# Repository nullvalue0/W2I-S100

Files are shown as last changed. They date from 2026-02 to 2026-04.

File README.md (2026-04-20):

S-100 Board Version of Mike Arnold's W2I (WDI to IDE adapter), for emulating up to four 11Mb IMI7710A drives. It is compatible with CDOS, Z80 Cromix, 68000 Cromix and Cromix Plus. It works with the Cromemco WDI and WDI-II controller. 

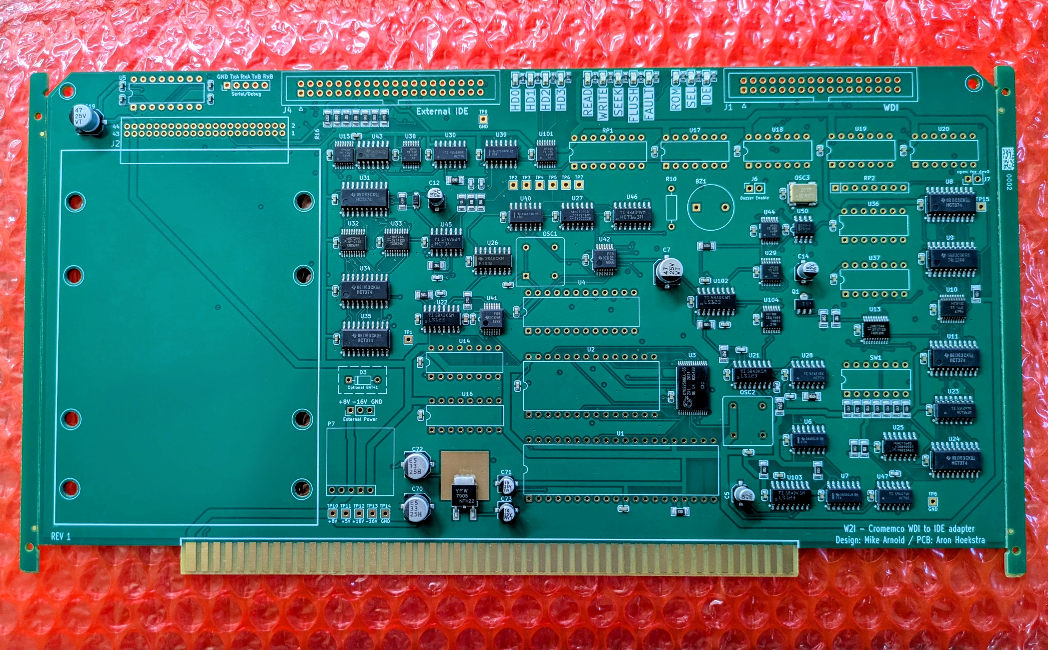
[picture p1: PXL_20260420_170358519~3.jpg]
First Prototype Photo


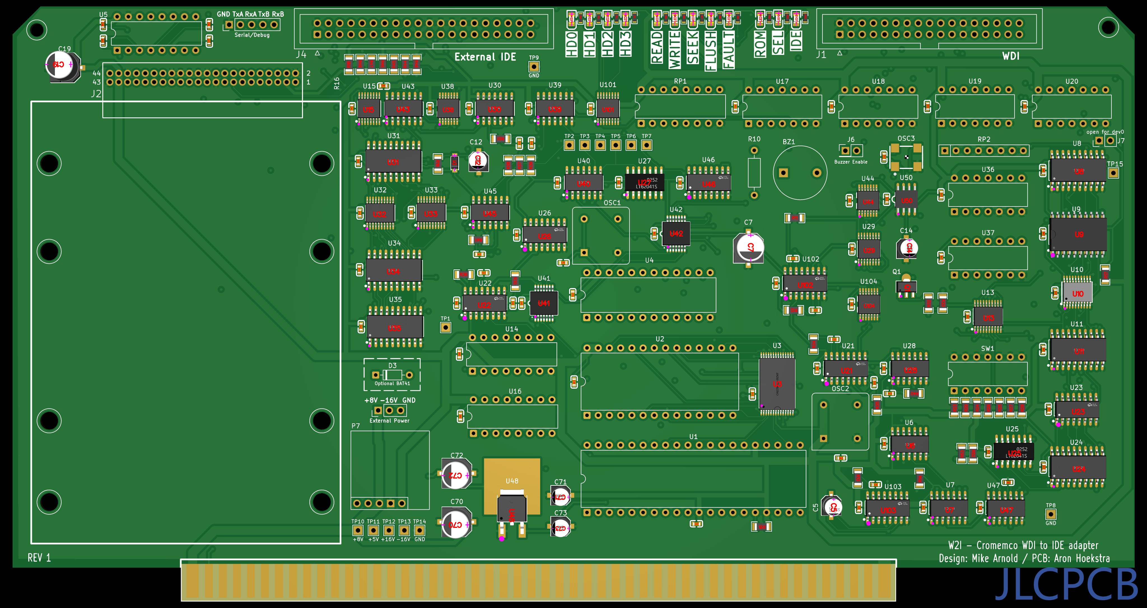
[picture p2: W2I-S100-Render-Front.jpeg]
PCB Front Render


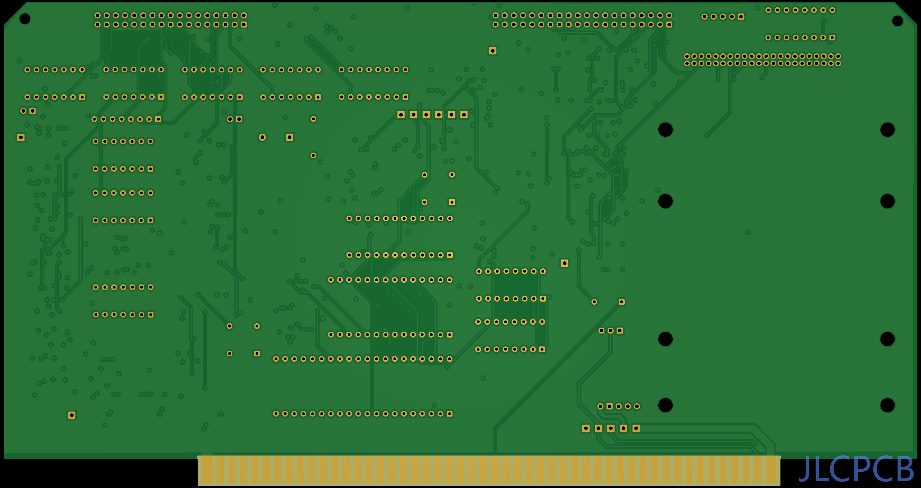
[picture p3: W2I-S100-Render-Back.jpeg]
PCB Back Render


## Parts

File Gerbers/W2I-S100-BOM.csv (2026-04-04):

Reference | Qty | Value | LCSC Part | DNP | Exclude from BOM | Exclude from Board | Footprint | Datasheet
BZ1 | 1 | PKHPS0013E4000-A2 |  |  |  |  | Buzzer_Beeper:Buzzer_12x9.5RM7.6 | ~
C1,C6,C8,C9,C10,C11,C13,C15,C16,C17,C18,C24,C25,C26,C27,C28,C29,C30,C31,C32,C36,C37,C38,C40,C41,C42,C44,C45,C46,C47,C48,C49,C50,C51,C52,C53,C54,C55,C56,C57,C58,C59,C60,C61,C62,C63,C64,C65,C66,C67,C68,C69,C74,C75,C77,C78 | 56 | 0.1uF | C1590 |  |  |  | footprints:C0603 | https://lcsc.com/product-detail/Multilayer-Ceramic-Capacitors-MLCC-SMD-SMT_SAMSUNG_CL10B104KA8NNNC_100nF-104-10-25V_C1590.html
C2,C3,C4 | 3 | 1.0uF | C29936 |  |  |  | footprints:C0603 | https://lcsc.com/product-detail/Multilayer-Ceramic-Capacitors-MLCC-SMD-SMT_SAMSUNG_CL10B104KA8NNNC_100nF-104-10-25V_C1590.html
C5 | 1 | 4.7uF | C264246 |  |  |  | footprints:CAP-SMD_BD4.0-L4.3-W4.3-LS5.3-FD | https://lcsc.com/product-detail/Others_Semtech-CK1E4R7M0405_C264246.html
C7,C19 | 2 | 47uF | C141425 |  |  |  | footprints:CAP-SMD_BD6.3-L6.6-W6.6-FD | https://lcsc.com/product-detail/Aluminum-Electrolytic-Capacitors-SMD_47uF-20-25V_C141425.html
C12,C14,C71,C73 | 4 | 10uF | C3343 |  |  |  | footprints:CAP-SMD_BD4.0-L4.3-W4.3-FD | https://lcsc.com/product-detail/Aluminum-Electrolytic-Capacitors-SMD_10uF-25V_C3343.html
C20 | 1 | 22uF | C2762594 |  |  |  | footprints:C0603
C21,C22,C23 | 3 | 470pF | C519395 |  |  |  | footprints:C0603 | ~
C33,C34,C35,C39 | 4 | 47pF | C519392 |  |  |  | footprints:C0603 | ~
C43 | 1 | 22pF | C519390 |  |  |  | footprints:C0603 | ~
C70,C72 | 2 | 33uF | C249892 |  |  |  | footprints:CAP-SMD_BD6.3-L6.6-W6.6-FD | https://lcsc.com/product-detail/Others_Lelon-VZH330M1E0606-TRO_C249892.html,https://lcsc.com/product-detail/Others_Semtech-CK1E4R7M0405_C264246.html
C76 | 1 | .33uF | C1615 |  |  |  | footprints:C0603 | https://lcsc.com/product-detail/Multilayer-Ceramic-Capacitors-MLCC-SMD-SMT_330nF-334-10-25V_C1615.html
D1 | 1 | 1N4148W T4 | C2099 |  |  |  | footprints:SOD-123_L2.8-W1.8-LS3.7-RD | https://lcsc.com/product-detail/Switching-Diode_1N4148W-T4_C2099.html
D3 | 1 | BAT41 |  |  |  |  | Diode_THT:D_DO-35_SOD27_P7.62mm_Horizontal | http://www.vishay.com/docs/85659/bat41.pdf
J1 | 1 | to WDI |  |  |  |  | Connector_IDC:IDC-Header_2x17_P2.54mm_Vertical | SBH11-PBPC-D17-ST-BK
J2 | 1 | 44-pin IDE |  |  |  |  | footprints:SAMTEC-SQT-122-01-X-D-RA
J3 | 1 | Serial |  |  |  |  | Connector_PinHeader_2.54mm:PinHeader_1x05_P2.54mm_Vertical | ~
J4 | 1 | 40-pin IDE |  |  |  |  | Connector_IDC:IDC-Header_2x20_P2.54mm_Vertical | ~
J5 | 1 | EXT PWR |  |  |  |  | Connector_PinHeader_2.54mm:PinHeader_1x03_P2.54mm_Vertical | ~
J6 | 1 | Jumper to enable buzzer |  |  |  |  | Connector_PinHeader_2.54mm:PinHeader_2x01_P2.54mm_Vertical | ~
J7 | 1 | Conn_01x02_Pin |  |  |  |  | Connector_PinHeader_2.54mm:PinHeader_1x02_P2.54mm_Vertical | ~
LED1,LED2,LED3,LED4 | 4 | YELLOW | C84261 |  |  |  | footprints:LED0805-R-RD | https://lcsc.com/product-detail/Light-Emitting-Diodes-LED_Yellow-light-SMDLED-80-150mcd_C84261.html
LED5,LED7,LED8 | 3 | GREEN | C84260 |  |  |  | footprints:LED0805-R-RD | https://lcsc.com/product-detail/Light-Emitting-Diodes-LED_Emerald-SMDLED-180-330mcd_C84260.html
LED6,LED9,LED11,LED12,LED13 | 5 | RED | C84256 |  |  |  | footprints:LED0805-R-RD | https://lcsc.com/product-detail/Light-Emitting-Diodes-LED_Red-LED-SMDLED-80-180mcd_C84256.html
OSC1 | 1 | ECS-2100AX-3.6864MHZ |  |  |  |  | Oscillator:Oscillator_DIP-8 | http://cdn-reichelt.de/documents/datenblatt/B400/OSZI.pdf
OSC2 | 1 | ACHL-27.000MHZ-EK |  |  |  |  | Oscillator:Oscillator_DIP-8 | http://cdn-reichelt.de/documents/datenblatt/B400/OSZI.pdf
OSC3 | 1 | 22.5792MHz | C7431407 |  |  |  | footprints:OSC-SMD_4P-L7.0-W5.0-BL-2
P1 | 1 | S100_MALE
P7 | 1 | 5V Reg |  |  |  |  | Connector_PinHeader_2.54mm:PinHeader_1x05_P2.54mm_Vertical | ~
Q1 | 1 | 2N2222AU | C21714170 |  |  |  | footprints:SOT-89-3_L4.5-W2.4-P1.50-LS4.0-BR
R1,R2,R3,R4 | 4 | 270 | C22966 |  |  |  | footprints:R0603 | https://lcsc.com/product-detail/Chip-Resistor-Surface-Mount-UniOhm_270R-2700-1_C22966.html
R5,R7,R8 | 3 | 160 | C22814 |  |  |  | footprints:R0603 | https://lcsc.com/product-detail/Chip-Resistor-Surface-Mount-UniOhm_470R-4700-1_C4502.html
R6,R9,R22,R31,R50 | 5 | 360 | C25194 |  |  |  | footprints:R0603 | https://lcsc.com/product-detail/Chip-Resistor-Surface-Mount-UniOhm_360R-3600-1_C25194.html
R10 | 1 | 330 |  |  |  |  | Resistor_THT:R_Axial_DIN0207_L6.3mm_D2.5mm_P10.16mm_Horizontal | ~
R11,R12,R13 | 3 | 100K | C17900 |  |  |  | footprints:R1206 | https://lcsc.com/product-detail/Chip-Resistor-Surface-Mount-UniOhm_100KR-1003-1_C17900.html
R14,R30 | 2 | 270K | C17940 |  |  |  | footprints:R1206 | https://lcsc.com/product-detail/Chip-Resistor-Surface-Mount-UniOhm_270KR-2703-1_C17940.html
R15,R17,R23,R24,R25,R26,R27,R28,R29 | 9 | 4.7K | C17936 |  |  |  | footprints:R1206 | https://lcsc.com/product-detail/Chip-Resistor-Surface-Mount-UniOhm_15KR-1502-1_C25828.html,https://lcsc.com/product-detail/Chip-Resistor-Surface-Mount-UniOhm_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
R16 | 1 | 22K | C114942 |  |  |  | footprints:R1206 | https://lcsc.com/product-detail/Chip-Resistor-Surface-Mount-UniOhm_5-6KR-5601-1_C18028.html
R18 | 1 | 47K | C25833 |  |  |  | footprints:R1206 | https://lcsc.com/product-detail/Chip-Resistor-Surface-Mount-UniOhm_47KR-4702-1_C25833.html
R32 | 1 | 2.2K | C17948 |  |  |  | footprints:R1206 | https://lcsc.com/product-detail/Chip-Resistor-Surface-Mount-UniOhm_2-2KR-2201-1_C17948.html
R33,R37,R39,R41,R46,R47,R52 | 7 | 1K | C1469 |  |  |  | footprints:R1206 | https://lcsc.com/product-detail/Chip-Resistor-Surface-Mount-UniOhm_1KR-102-5_C1469.html
R34,R35,R36 | 3 | 15K | C25828 |  |  |  | footprints:R1206 | https://lcsc.com/product-detail/Chip-Resistor-Surface-Mount-UniOhm_15KR-1502-1_C25828.html
R38,R53 | 2 | 1.5K | C26030 |  |  |  | footprints:R1206 | https://lcsc.com/product-detail/Chip-Resistor-Surface-Mount-UniOhm_1-5KR-1501-1_C26030.html
R40 | 1 | 470 | C4502 |  |  |  | footprints:R1206 | https://lcsc.com/product-detail/Chip-Resistor-Surface-Mount-UniOhm_470R-4700-1_C4502.html
R44,R45 | 2 | 33 | C18005 |  |  |  | footprints:R1206 | https://lcsc.com/product-detail/Chip-Resistor-Surface-Mount-UniOhm_33R-33R0-1_C18005.html
R48 | 1 | 5.6K | C18028 |  |  |  | footprints:R1206 | https://lcsc.com/product-detail/Chip-Resistor-Surface-Mount-UniOhm_5-6KR-5601-1_C18028.html
R49 | 1 | 10K | C17902 |  |  |  | footprints:R1206 | https://lcsc.com/product-detail/Chip-Resistor-Surface-Mount-UniOhm_10KR-1002-1_C17902.html
R51 | 1 | 100 | C17901 |  |  |  | footprints:R1206 | https://lcsc.com/product-detail/Chip-Resistor-Surface-Mount-UniOhm_100R-1000-1_C17901.html
RP1 | 1 | 4116R-3-221/331 |  |  |  |  | Package_DIP:DIP-16_W7.62mm | ~
RP2 | 1 | 4x100Ω |  |  |  |  | Resistor_THT:R_Array_SIP8 | http://www.vishay.com/docs/31509/csc.pdf
SW1 | 1 | SW_DIP_x07 |  |  |  |  | Package_DIP:DIP-14_W7.62mm | ~
TP1 | 1 | 2s timer output |  |  |  |  | TestPoint:TestPoint_THTPad_2.0x2.0mm_Drill1.0mm | ~
TP2 | 1 | 50ns W60h pulse |  |  |  |  | TestPoint:TestPoint_THTPad_2.0x2.0mm_Drill1.0mm | ~
TP3 | 1 | 50ns R60h pulse |  |  |  |  | TestPoint:TestPoint_THTPad_2.0x2.0mm_Drill1.0mm | ~
TP4 | 1 | 50ns delayed W60h pulse |  |  |  |  | TestPoint:TestPoint_THTPad_2.0x2.0mm_Drill1.0mm | ~
TP5 | 1 | 50ns burst clock trigger |  |  |  |  | TestPoint:TestPoint_THTPad_2.0x2.0mm_Drill1.0mm | ~
TP6 | 1 | 50ns primer clock trigger |  |  |  |  | TestPoint:TestPoint_THTPad_2.0x2.0mm_Drill1.0mm | ~
TP7 | 1 | 22.579MHz clock |  |  |  |  | TestPoint:TestPoint_THTPad_2.0x2.0mm_Drill1.0mm | ~
TP8,TP9,TP14 | 3 | GND |  |  |  |  | TestPoint:TestPoint_THTPad_2.0x2.0mm_Drill1.0mm | ~
TP10 | 1 | +8V |  |  |  |  | TestPoint:TestPoint_THTPad_2.0x2.0mm_Drill1.0mm | ~
TP11 | 1 | +5V |  |  |  |  | TestPoint:TestPoint_THTPad_2.0x2.0mm_Drill1.0mm | ~
TP12 | 1 | +16V |  |  |  |  | TestPoint:TestPoint_THTPad_2.0x2.0mm_Drill1.0mm | ~
TP13 | 1 | -16V |  |  |  |  | TestPoint:TestPoint_THTPad_2.0x2.0mm_Drill1.0mm | ~
TP15 | 1 | U8-16 |  |  |  |  | TestPoint:TestPoint_THTPad_2.0x2.0mm_Drill1.0mm | ~
U1 | 1 | Z84C0020PEC |  |  |  |  | Package_DIP:DIP-40_W15.24mm | www.zilog.com/manage_directlink.php?filepath=docs/z80/um0080
U2 | 1 | 28C256 |  |  |  |  | Package_DIP:DIP-28_W15.24mm | http://ww1.microchip.com/downloads/en/DeviceDoc/doc0006.pdf
U3 | 1 | CY62256NLL-55ZXIT | C2759940 |  |  |  | footprints:TSOP-28_L11.8-W8.0-P0.55-LS13.4-B_CYPRESS
U4 | 1 | 2681 |  |  |  |  | Package_DIP:DIP-24_W10.16mm | ~
U5 | 1 | MAX232A |  |  |  |  | Package_DIP:DIP-16_W7.62mm | http://www.ti.com/lit/ds/symlink/max232.pdf
U6,U7 | 2 | 74F74 | C6805 |  |  |  | footprints:SOIC-14_L8.7-W3.9-P1.27-LS6.0-BL | https://lcsc.com/product-detail/74-Series_TI_SN74F74DR_SN74F74DR_C6805.html
U8,U11,U24,U31,U34,U35 | 6 | 74HCT374 | C2677828 |  |  |  | footprints:SOP-20_L12.6-W5.3-P1.27-LS7.8-BL | https://www.ti.com/lit/ds/symlink/cd74hct374.pdf
U9 | 1 | 74LS244 | C22374097 |  |  |  | footprints:SOP-20_L12.6-W5.3-P1.27-LS7.8-BL | http://www.ti.com/lit/ds/symlink/sn74ls244.pdf
U10 | 1 | 74HCT240 | C543088 |  |  |  | footprints:TSSOP-20_L6.5-W4.4-P0.65-LS6.5-BL | https://assets.nexperia.com/documents/data-sheet/74HC_HCT240.pdf
U13,U32,U33 | 3 | 74HCT244 | C131088 |  |  |  | footprints:TSSOP-20_L6.5-W4.4-P0.65-LS6.4-BL | http://www.ti.com/lit/ds/symlink/sn74ls244.pdf
U14,U16 | 2 | 74F138 |  |  |  |  | Package_DIP:DIP-16_W7.62mm | http://www.ti.com/lit/gpn/sn74LS138
U15,U29,U101 | 3 | 74HCT138 | C8115 |  |  |  | footprints:TSSOP-16_L5.0-W4.4-P0.65-LS6.4-BL | http://www.ti.com/lit/ds/symlink/cd74hc238.pdf
U17,U18,U19,U20 | 4 | 7438 |  |  |  |  | Package_DIP:DIP-14_W7.62mm | http://www.ti.com/lit/gpn/sn74LS38
U21,U22,U102,U103 | 4 | 74LS123 | C234231 |  |  |  | footprints:SOIC-16_L9.9-W3.9-P1.27-LS6.0-BL | http://www.ti.com/lit/gpn/sn74LS123
U23 | 1 | 74HCT165 | C352828 |  |  |  | footprints:SOIC-16_L9.9-W3.9-P1.27-LS6.0-BL | https://assets.nexperia.com/documents/data-sheet/74HC_HCT165.pdf
U25 | 1 | 74HCT164 | C547397 |  |  |  | footprints:SOIC-14_L8.7-W3.9-P1.27-LS6.0-BL | https://assets.nexperia.com/documents/data-sheet/74HC_HCT164.pdf
U26 | 1 | 74F163 | C2675415 |  |  |  | footprints:SOIC-16_L9.9-W3.9-P1.27-LS6.0-BL
U27 | 1 | 74HCT393 | C547642 |  |  |  | footprints:SO-14_L8.7-W3.9-P1.27-LS6.0-BL | 74xx\74LS393.pdf
U28,U30 | 2 | 74HCT74 | C352961 |  |  |  | footprints:SO-14_L8.9-W3.9-P1.27-LS6.0-BL | https://assets.nexperia.com/documents/data-sheet/74HC_HCT74.pdf
U36 | 1 | 75107 |  |  |  |  | Package_DIP:DIP-14_W7.62mm | ~
U37 | 1 | 75110 |  |  |  |  | Package_DIP:DIP-14_W7.62mm | ~
U38,U44 | 2 | 74HCT04 | C131695 |  |  |  | footprints:TSSOP-14_L5.0-W4.4-P0.65-LS6.4-BL | https://assets.nexperia.com/documents/data-sheet/74HC_HCT04.pdf
U39 | 1 | 74F04 | C7159 |  |  |  | footprints:SOIC-14_L8.7-W3.9-P1.27-LS6.0-BL | https://lcsc.com/product-detail/74-Series_TI_SN74F04DR_SN74F04DR_C7159.html
U40 | 1 | 74F00 | C7158 |  |  |  | footprints:SOIC-14_L8.7-W3.9-P1.27-LS6.0-BL | https://lcsc.com/product-detail/74-Series_TI_SN74F00DR_SN74F00DR_C7158.html
U41,U42 | 2 | 74F08 | C4469192 |  |  |  | footprints:SSOP-14_L6.2-W5.3-P0.65-LS7.8-BL-1
U43 | 1 | 74HCT32 | C6781 |  |  |  | footprints:SOIC-14_L8.7-W3.9-P1.27-LS6.0-BL | http://www.ti.com/lit/gpn/sn74LS32
U45 | 1 | 74HCT14 | C6769 |  |  |  | footprints:SOIC-14_L8.7-W3.9-P1.27-LS6.0-BL | http://www.ti.com/lit/gpn/sn74LS14
U46 | 1 | 74HCT163 | C2866759 |  |  |  | footprints:SOIC-16_L9.9-W3.9-P1.27-LS6.0-BL | http://www.ti.com/lit/gpn/sn74LS163
U47 | 1 | 74HCT02 | C471050 |  |  |  | footprints:SOIC-14_L8.7-W3.9-P1.27-LS6.0-BL | http://www.ti.com/lit/gpn/sn74hct02
U48 | 1 | 7905 | C19273129 |  |  |  | footprints:TO-252-2_L6.6-W6.1-P4.57-LS10.1-BR-CW
U50 | 1 | 3.3V LDO Reg | C7301 |  |  |  | footprints:SOIC-8_L5.0-W4.0-P1.27-LS6.0-BL | https://lcsc.com/product-detail/Low-Dropout-Regulators-LDO_ON_MC33269DR2-3-3_MC33269DR2-3-3_C7301.html
U104 | 1 | 74HCT00 | C8206 |  |  |  | footprints:TSSOP-14_L5.0-W4.4-P0.65-LS6.4-BL | http://www.ti.com/lit/gpn/sn74hct00

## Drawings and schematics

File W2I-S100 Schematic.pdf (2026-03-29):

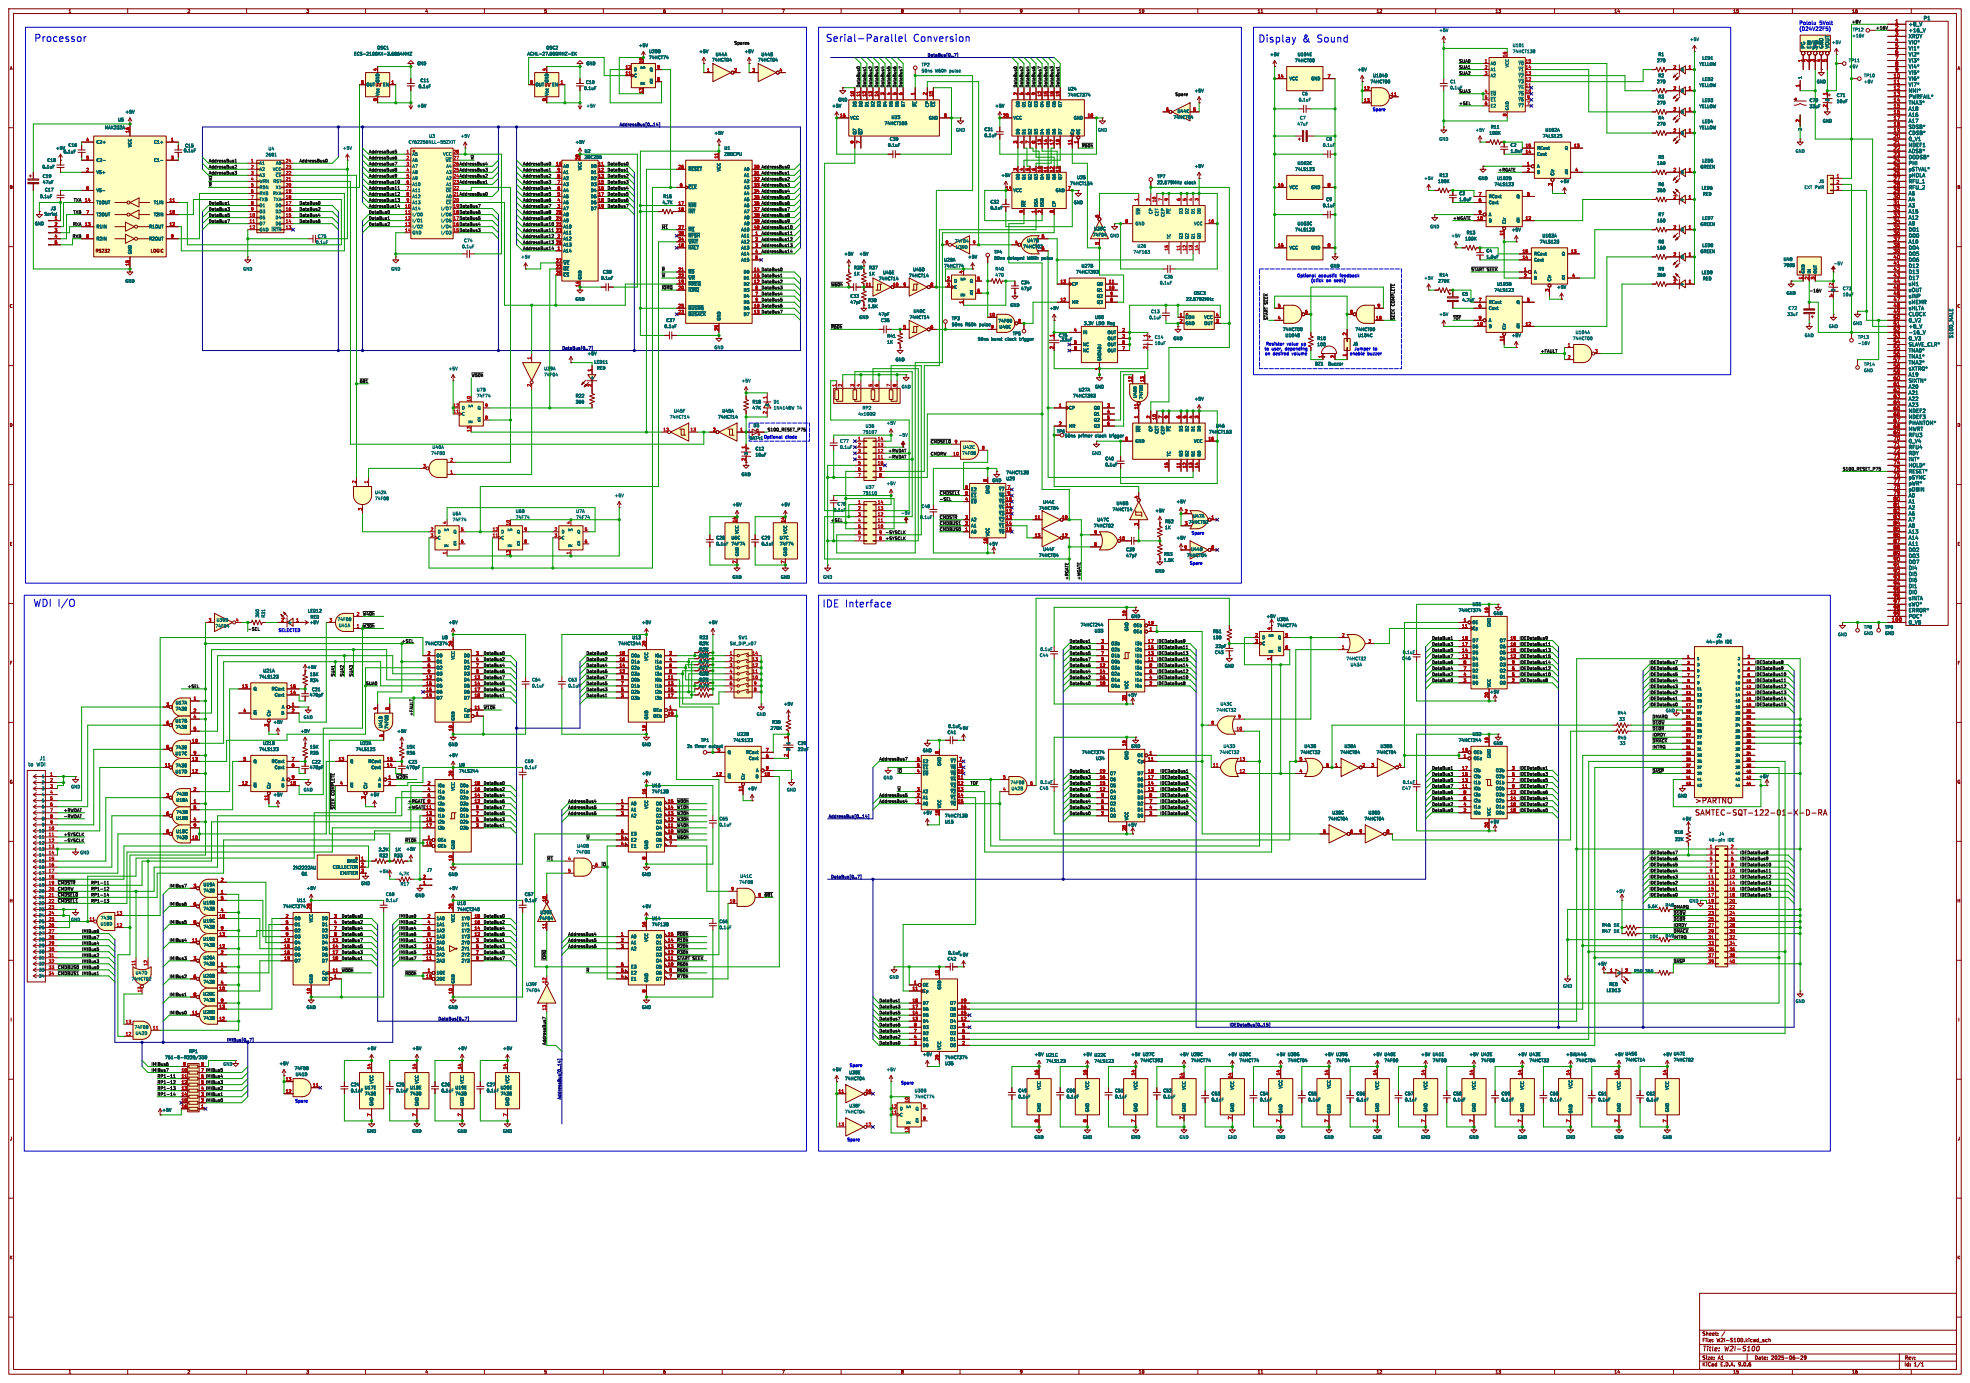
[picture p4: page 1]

9 ~{Q}8 OSC1 ECS-2100AX-3.6864MHZ EN 1 Vcc 8 GND

enable buzzer Resistor value up
to user, depending

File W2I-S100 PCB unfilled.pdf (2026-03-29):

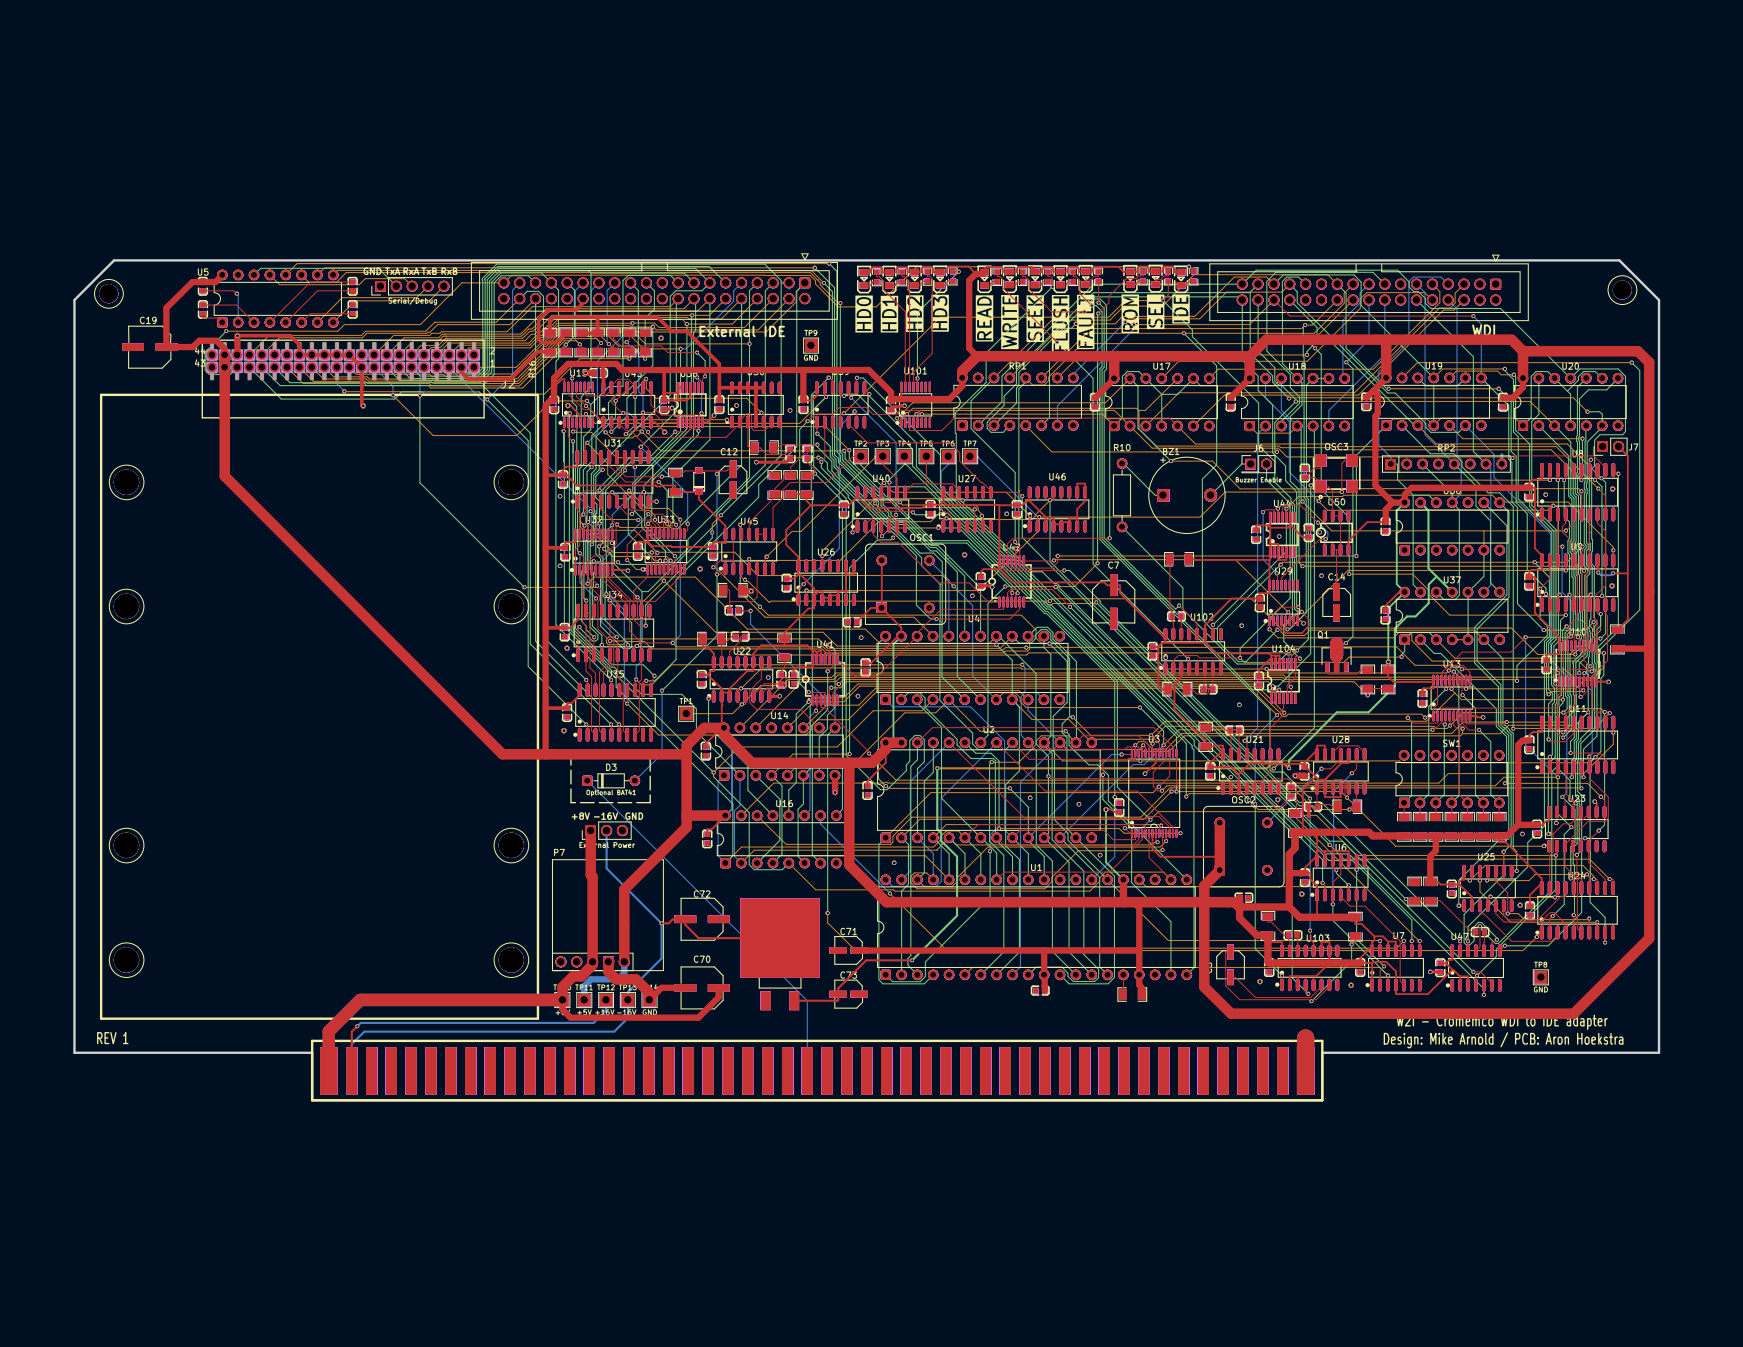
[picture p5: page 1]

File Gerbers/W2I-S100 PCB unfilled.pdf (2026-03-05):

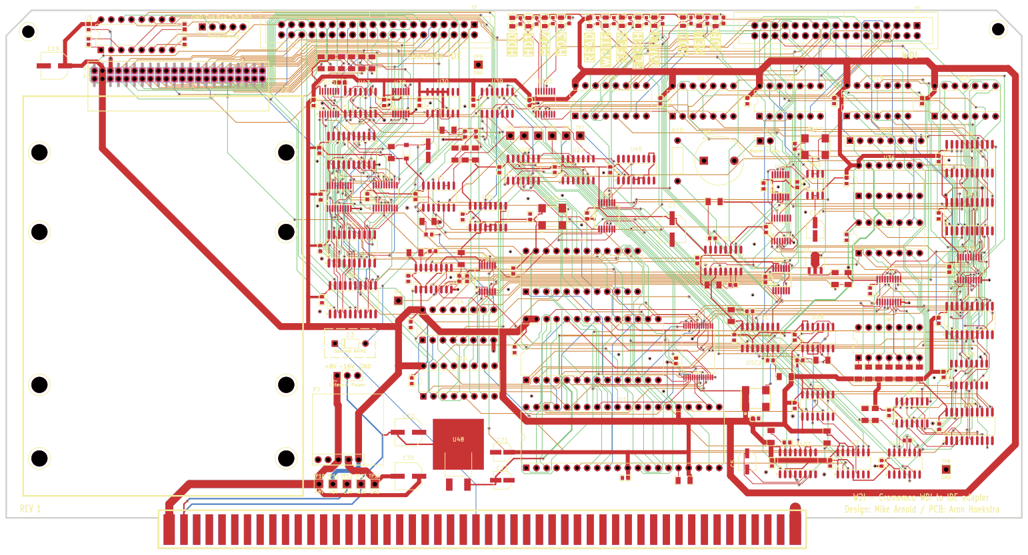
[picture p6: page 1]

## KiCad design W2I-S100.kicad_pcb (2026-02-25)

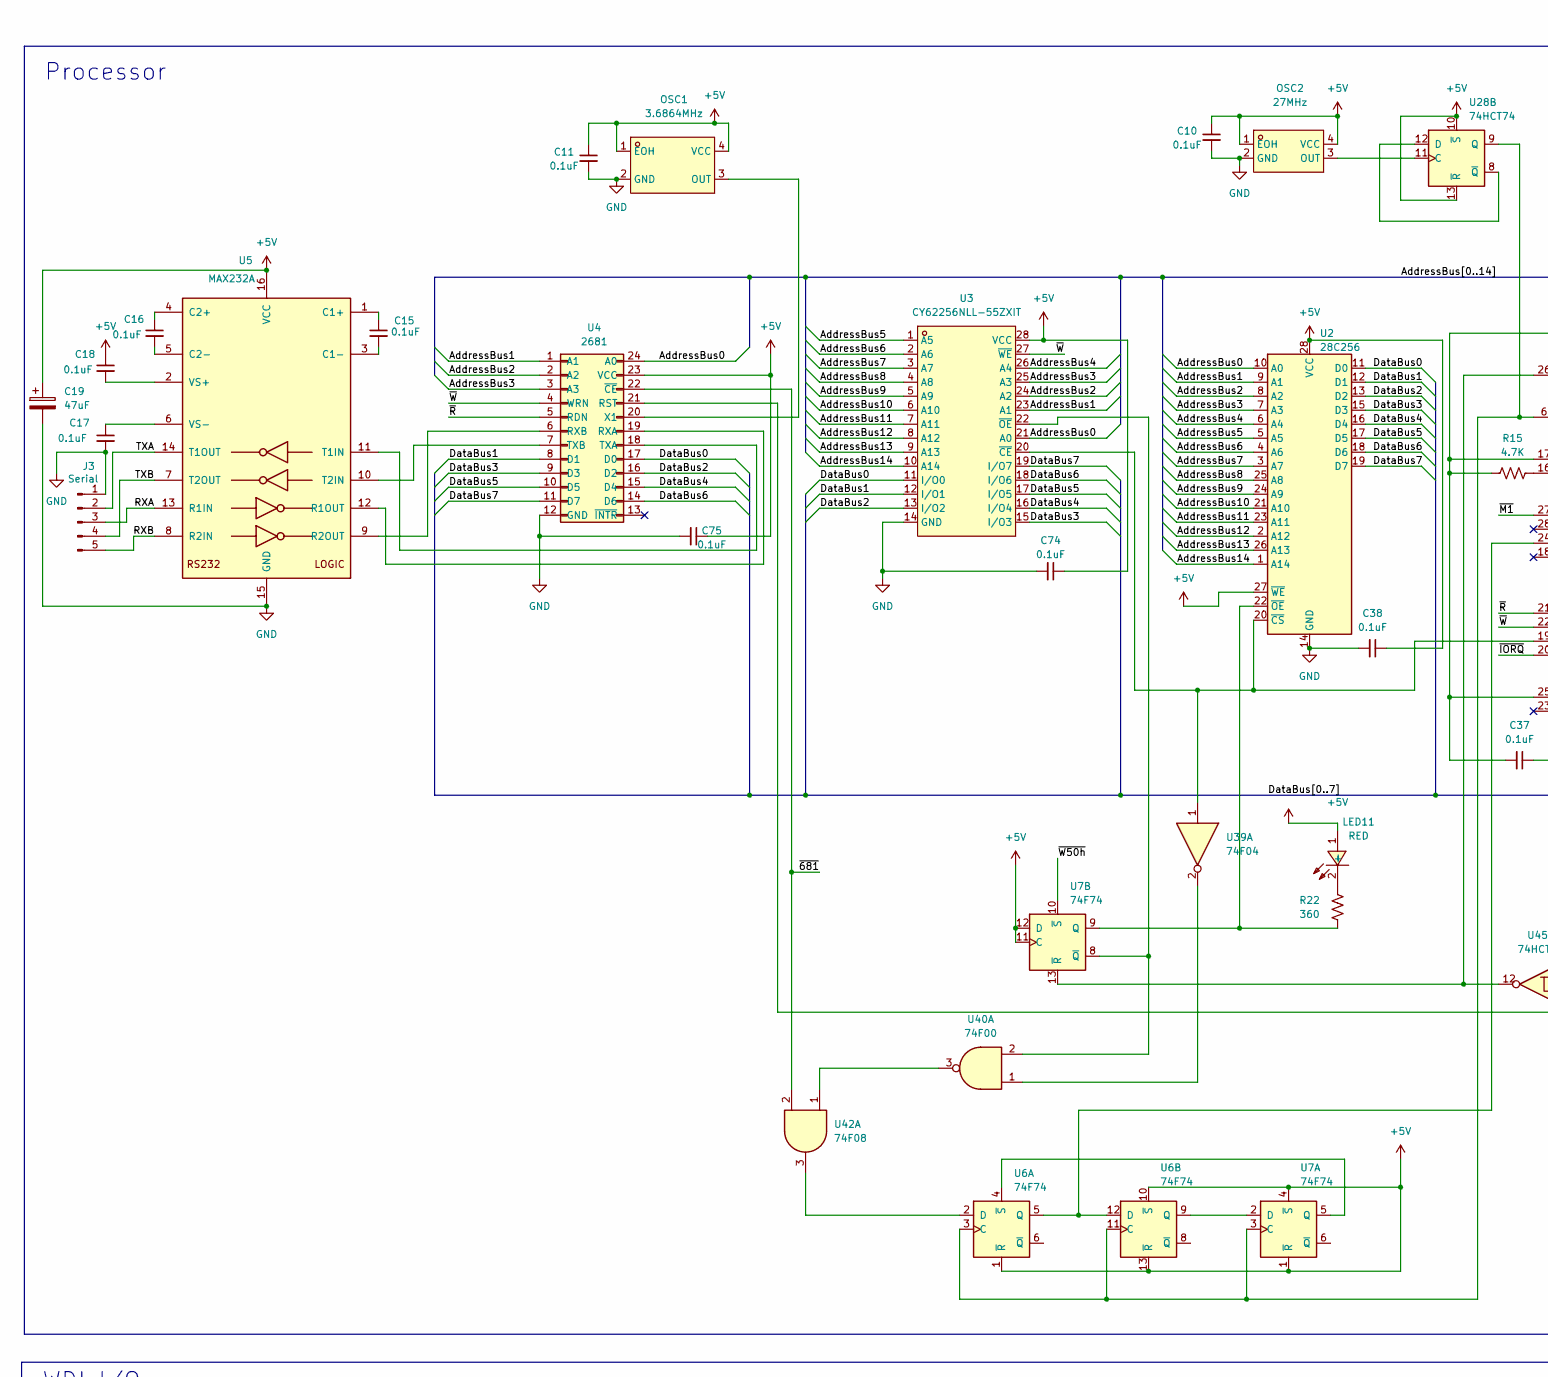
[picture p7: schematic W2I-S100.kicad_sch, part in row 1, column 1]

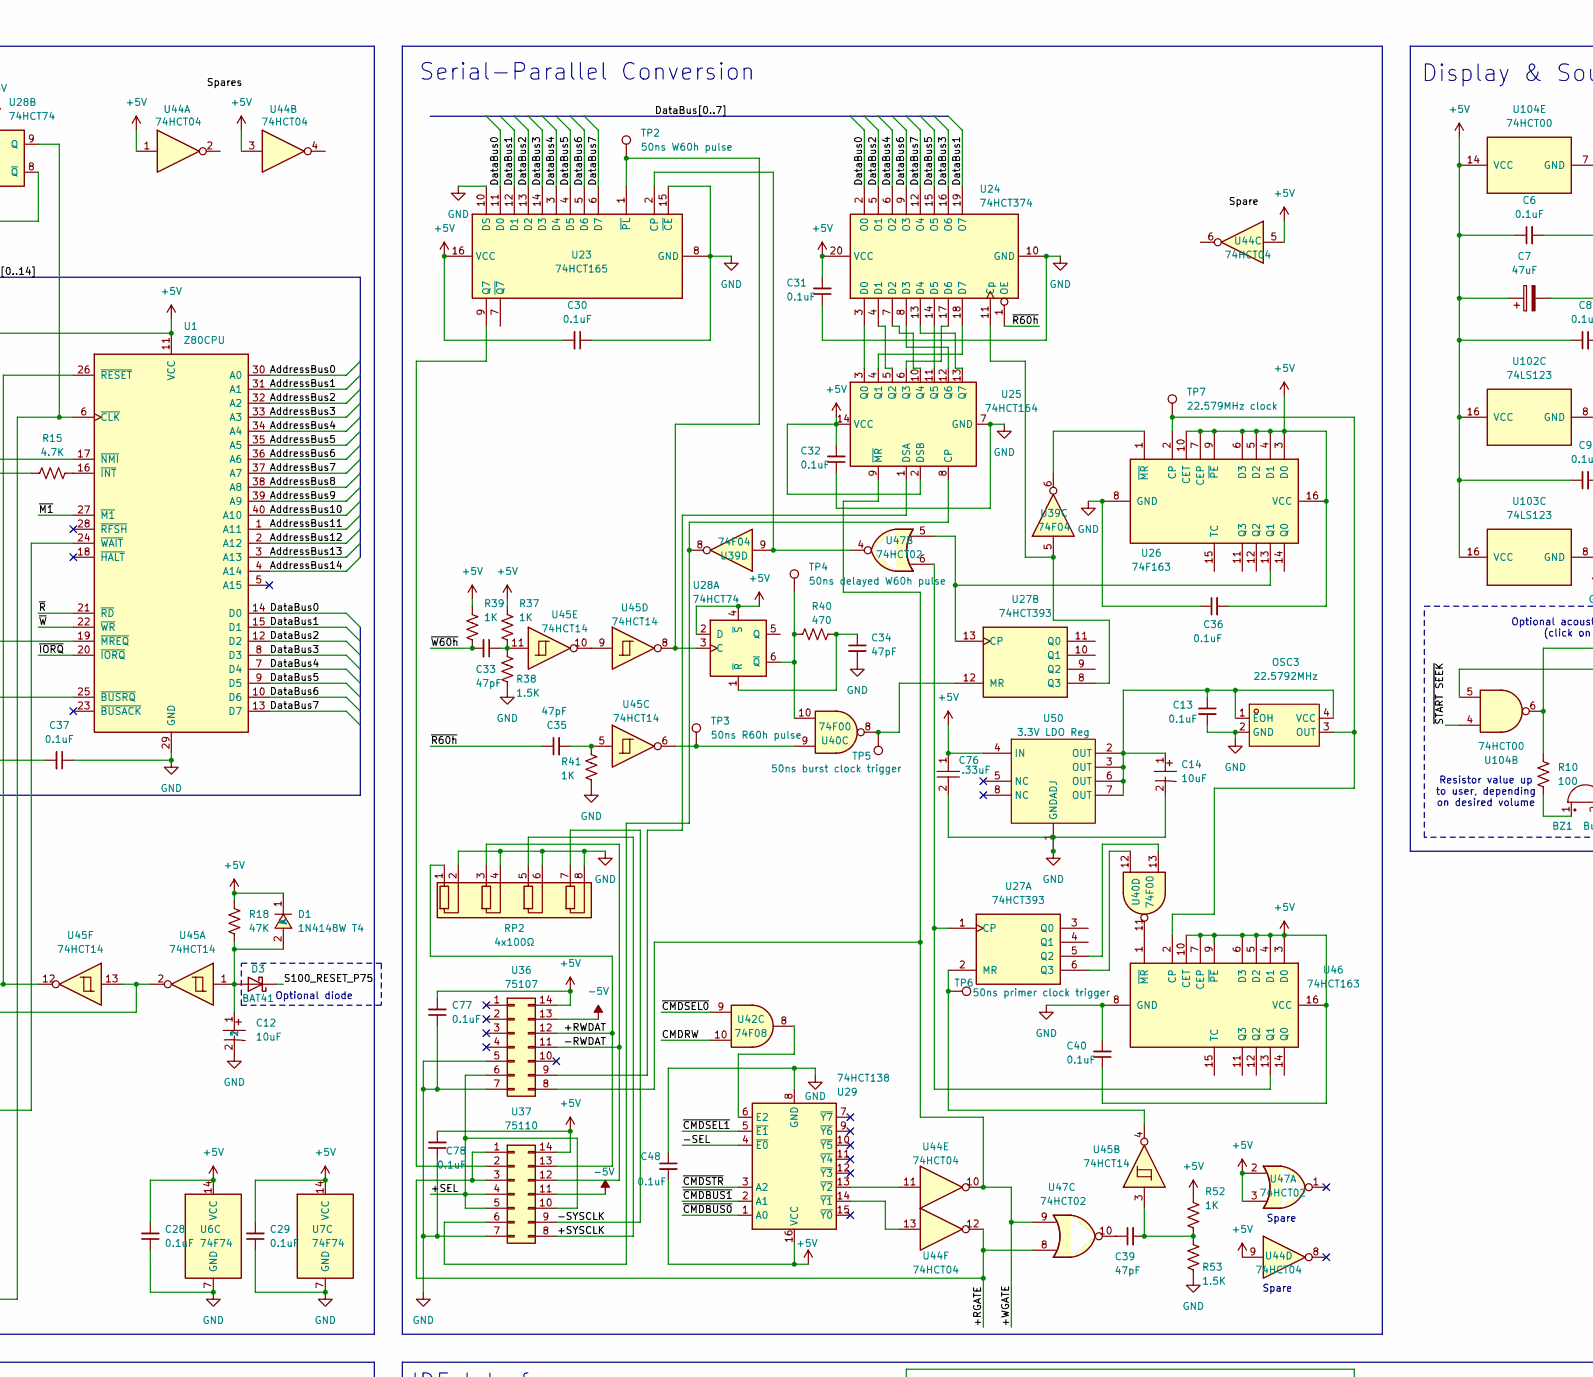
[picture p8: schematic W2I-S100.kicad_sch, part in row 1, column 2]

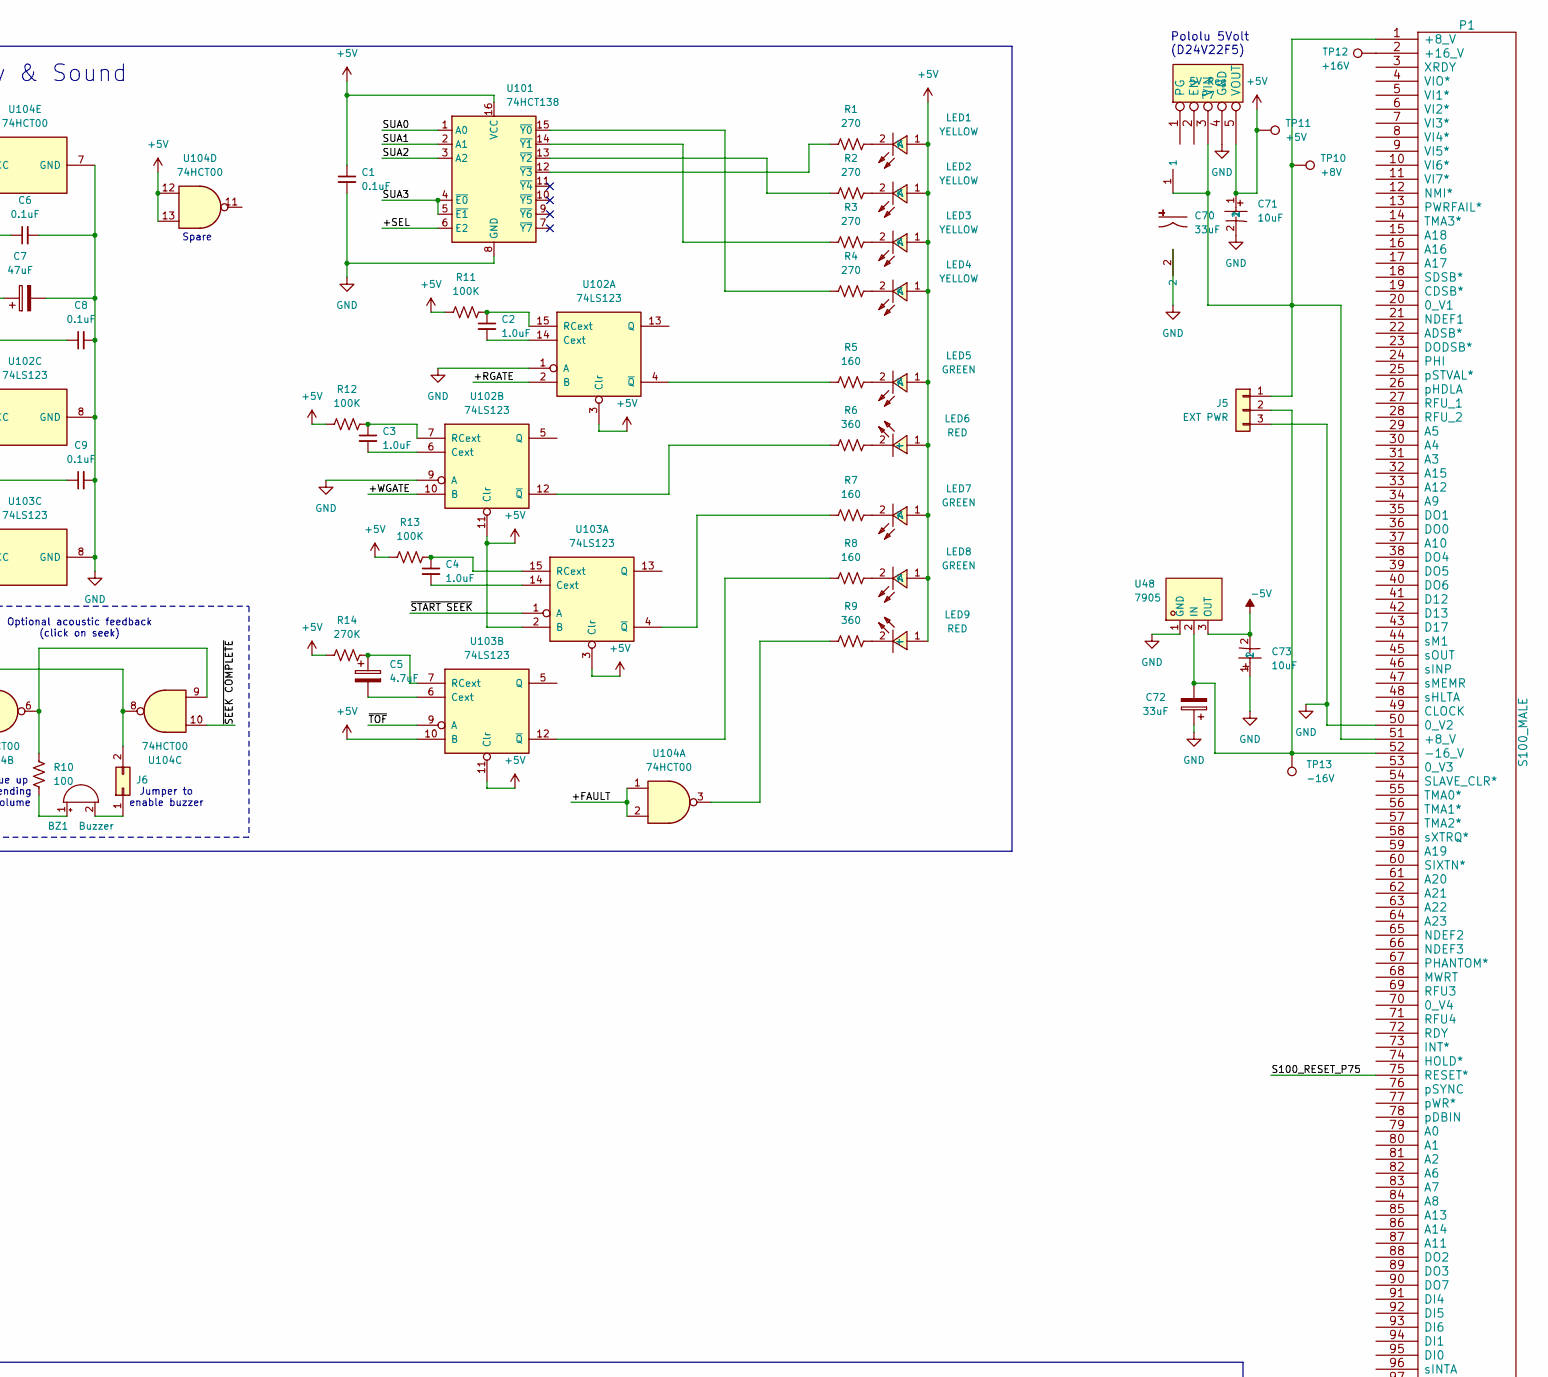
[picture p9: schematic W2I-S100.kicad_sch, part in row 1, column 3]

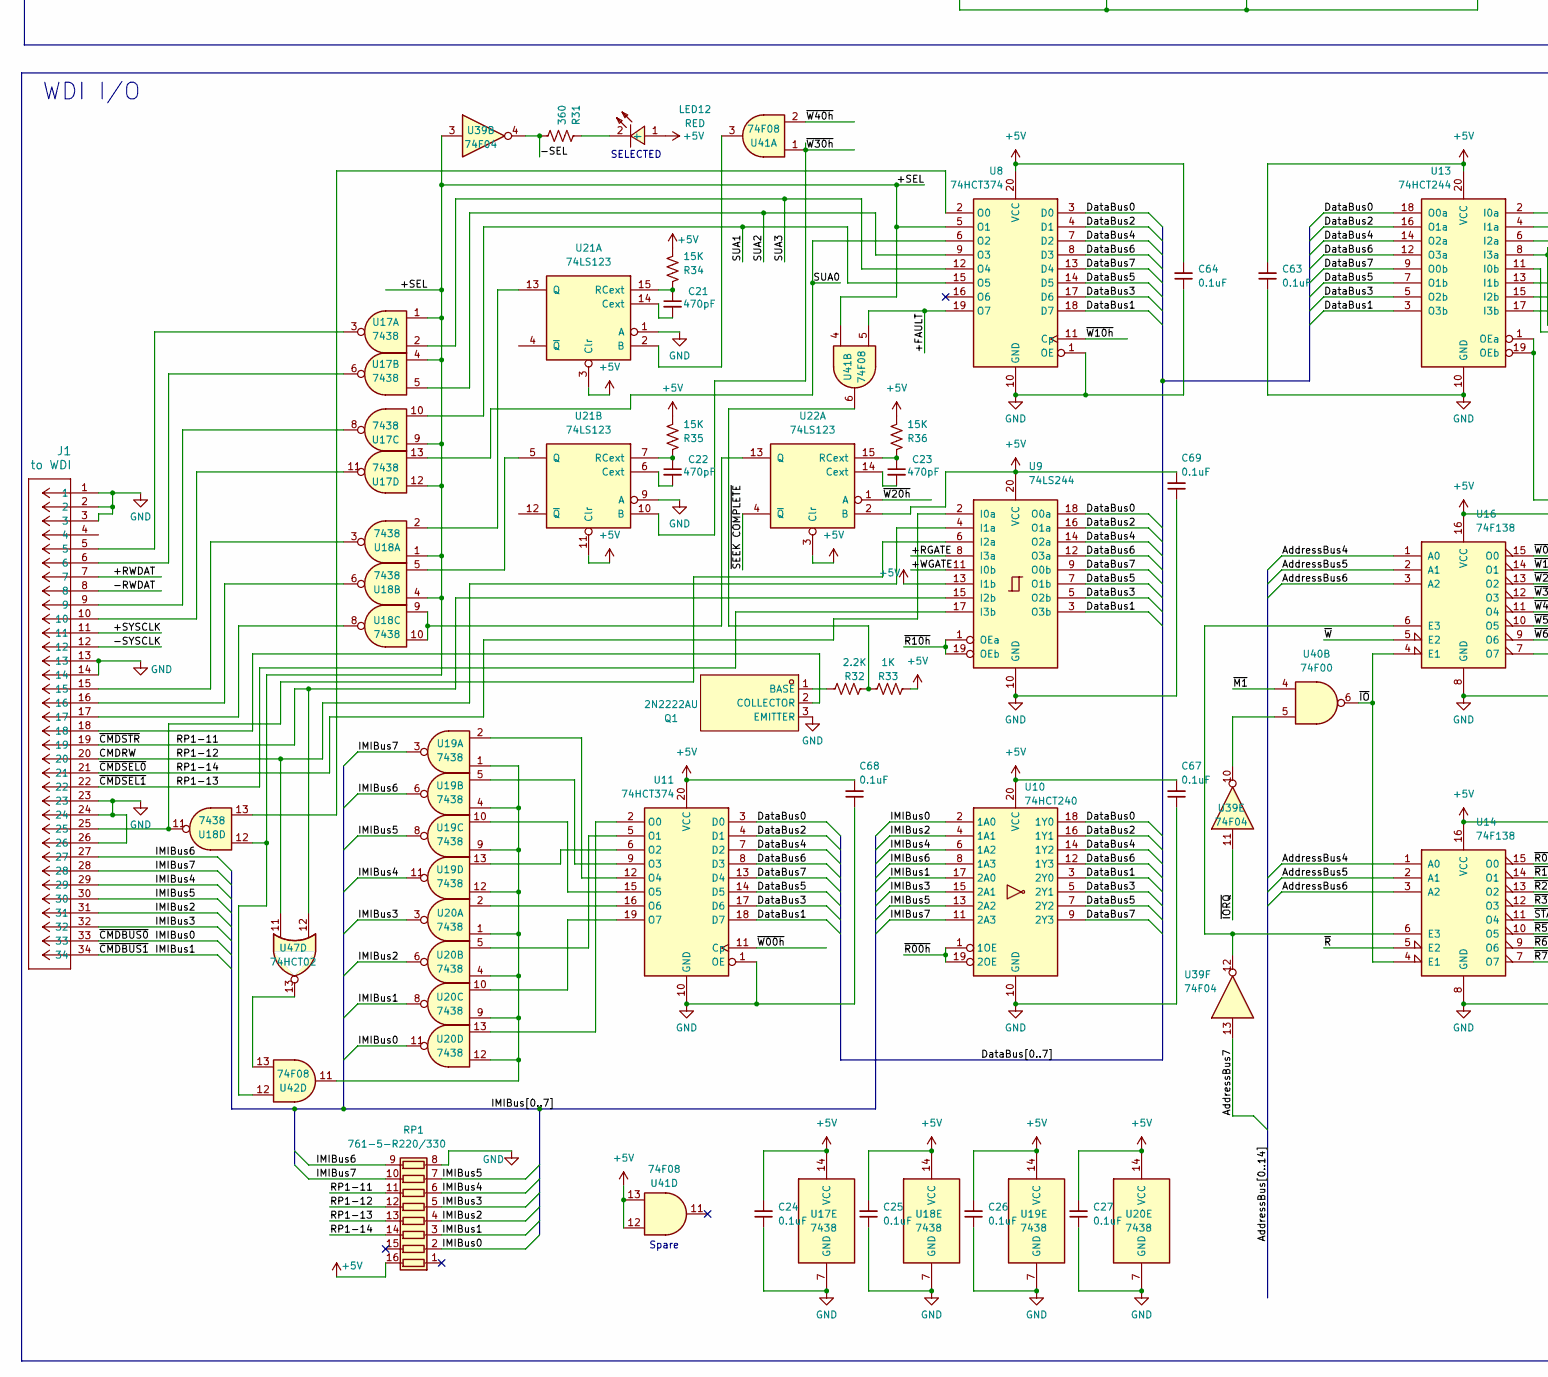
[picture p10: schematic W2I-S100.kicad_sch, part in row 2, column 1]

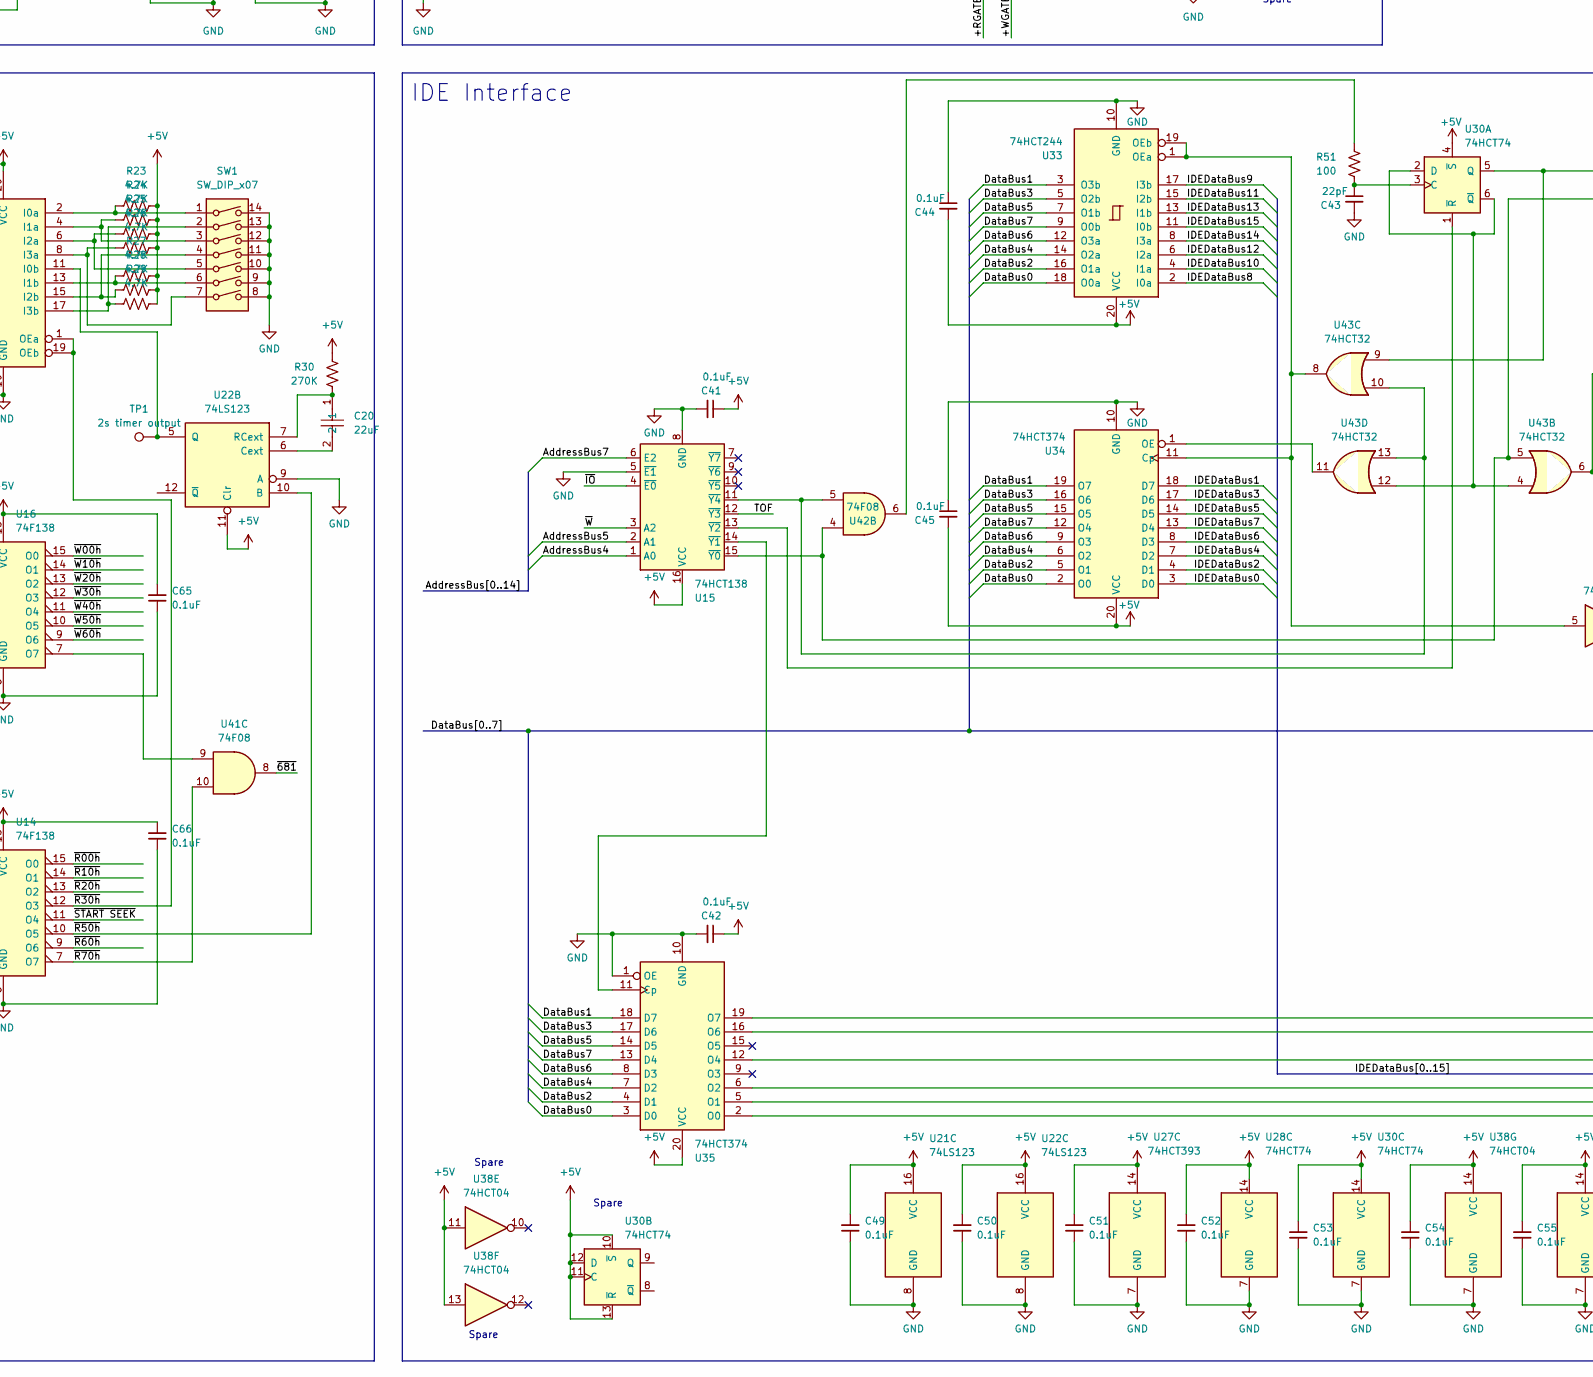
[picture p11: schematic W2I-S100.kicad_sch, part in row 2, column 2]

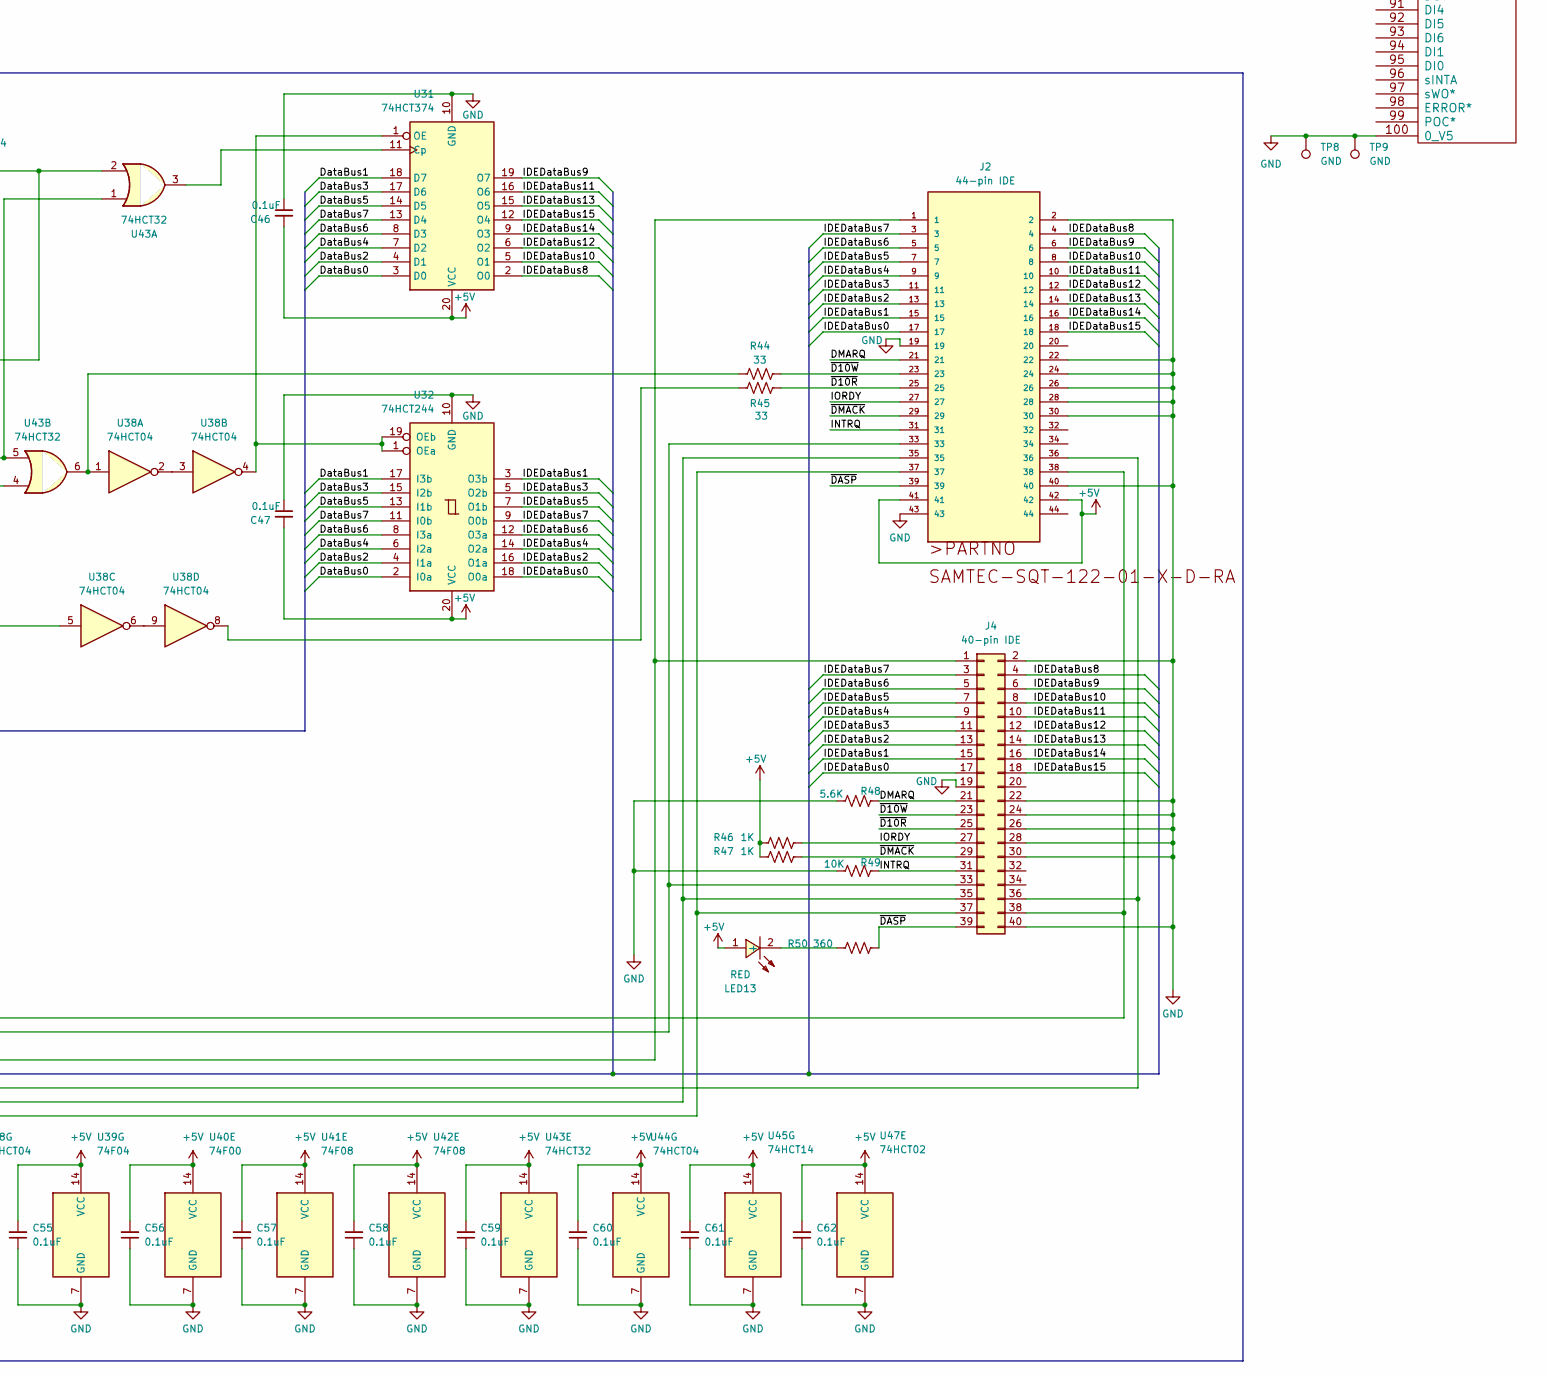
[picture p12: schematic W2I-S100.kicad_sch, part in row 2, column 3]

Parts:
BZ1: Buzzer; Buzzer_12x9.5RM7.6
C1, C6, C8, C9, C10, C11, C13, C15, C16, C17, C18, C24, C25, C26, C27, C28, C29, C30, C31, C32, C36, C37, C38, C40, C41, C42, C44, C45, C46, C47, C48, C49, C50, C51, C52, C53, C54, C55, C56, C57, C58, C59, C60, C61, C62, C63, C64, C65, C66, C67, C68, C69, C74, C75, C77, C78: 0.1uF; C0603; LCSC Part C1590
C2, C3, C4: 1.0uF; C0603; LCSC Part C29936
C5: 4.7uF; CAP-SMD_BD4.0-L4.3-W4.3-LS5.3-FD; LCSC Part C264246
C7, C19: 47uF; CAP-SMD_BD6.3-L6.6-W6.6-FD; LCSC Part C141425
C12, C14, C71, C73: 10uF; CAP-SMD_BD4.0-L4.3-W4.3-FD; LCSC Part C3343
C20: 22uF; C0603; LCSC Part C2762594
C21, C22, C23: 470pF; C0603; LCSC Part C519395
C33, C34, C35, C39: 47pF; C0603; LCSC Part C519392
C43: 22pF; C0603; LCSC Part C519390
C70, C72: 33uF; CAP-SMD_BD6.3-L6.6-W6.6-FD; LCSC Part C249892
C76: .33uF; C0603; LCSC Part C1615
D1: 1N4148W T4; SOD-123_L2.8-W1.8-LS3.7-RD; LCSC Part C2099
D3: BAT41; D_DO-35_SOD27_P7.62mm_Horizontal
J1: to WDI; IDC-Header_2x17_P2.54mm_Vertical
J2: 44-pin IDE; SAMTEC-SQT-122-01-X-D-RA
J3: Serial; PinHeader_1x05_P2.54mm_Vertical
J4: 40-pin IDE; IDC-Header_2x20_P2.54mm_Vertical
J5: EXT PWR; PinHeader_1x03_P2.54mm_Vertical
J6: Jumper to enable buzzer; PinHeader_2x01_P2.54mm_Vertical
LED1, LED2, LED3, LED4: YELLOW; LED0805-R-RD; LCSC Part C84261
LED5, LED7, LED8: GREEN; LED0805-R-RD; LCSC Part C84260
LED6, LED9, LED11, LED12, LED13: RED; LED0805-R-RD; LCSC Part C84256
OSC1: 3.6864MHz; OSC-SMD_4P-L7.0-W5.0-BL-2; LCSC Part C1851439
OSC2: 27MHz; OSC-SMD_4P-L7.0-W5.0-BL-2; LCSC Part C1851667
OSC3: 22.5792MHz; OSC-SMD_4P-L7.0-W5.0-BL-2; LCSC Part C7431407
P1: S100_MALE
P7: 5V Reg; PinHeader_1x05_P2.54mm_Vertical
Q1: 2N2222AU; SOT-89-3_L4.5-W2.4-P1.50-LS4.0-BR; LCSC Part C21714170
R1, R2, R3, R4: 270; R0603; LCSC Part C22966
R5, R7, R8: 160; R0603; LCSC Part C22814
R6, R9, R22, R31, R50: 360; R0603; LCSC Part C25194
R10: 100; R_Axial_DIN0207_L6.3mm_D2.5mm_P10.16mm_Horizontal
R11, R12, R13: 100K; R1206; LCSC Part C17900
R14, R30: 270K; R1206; LCSC Part C17940
R15, R23, R24, R25, R26, R27, R28, R29: 4.7K; R1206; LCSC Part C17936
R18: 47K; R1206; LCSC Part C25833
R32: 2.2K; R1206; LCSC Part C17948
R33, R37, R39, R41, R46, R47, R52: 1K; R1206; LCSC Part C1469
R34, R35, R36: 15K; R1206; LCSC Part C25828
R38, R53: 1.5K; R1206; LCSC Part C26030
R40: 470; R1206; LCSC Part C4502
R44, R45: 33; R1206; LCSC Part C18005
R48: 5.6K; R1206; LCSC Part C18028
R49: 10K; R1206; LCSC Part C17902
R51: 100; R1206; LCSC Part C17901
RP1: 761-5-R220/330; DIP-16_W7.62mm
RP2: 4x100Ω; R_Array_SIP8
SW1: SW_DIP_x07; DIP-14_W7.62mm
TP1: 2s timer output; TestPoint_THTPad_2.0x2.0mm_Drill1.0mm
TP2: 50ns W60h pulse; TestPoint_THTPad_2.0x2.0mm_Drill1.0mm
TP3: 50ns R60h pulse; TestPoint_THTPad_2.0x2.0mm_Drill1.0mm
TP4: 50ns delayed W60h pulse; TestPoint_THTPad_2.0x2.0mm_Drill1.0mm
TP5: 50ns burst clock trigger; TestPoint_THTPad_2.0x2.0mm_Drill1.0mm
TP6: 50ns primer clock trigger; TestPoint_THTPad_2.0x2.0mm_Drill1.0mm
TP7: 22.579MHz clock; TestPoint_THTPad_2.0x2.0mm_Drill1.0mm
TP8, TP9: GND; TestPoint_THTPad_2.0x2.0mm_Drill1.0mm
TP10: +8V; TestPoint_THTPad_2.0x2.0mm_Drill1.0mm
TP11: +5V; TestPoint_THTPad_2.0x2.0mm_Drill1.0mm
TP12: +16V; TestPoint_THTPad_2.0x2.0mm_Drill1.0mm
TP13: -16V; TestPoint_THTPad_2.0x2.0mm_Drill1.0mm
U1: Z80CPU; DIP-40_W15.24mm
U2: 28C256; DIP-28_W15.24mm
U3: CY62256NLL-55ZXIT; TSOP-28_L11.8-W8.0-P0.55-LS13.4-B_CYPRESS; LCSC Part C2759940
U4: 2681; DIP-24_W10.16mm
U5: MAX232A; DIP-16_W7.62mm
U6, U7: 74F74; SOIC-14_L8.7-W3.9-P1.27-LS6.0-BL; LCSC Part C6805
U8, U11, U24, U31, U34, U35: 74HCT374; SOP-20_L12.6-W5.3-P1.27-LS7.8-BL; LCSC Part C2677828
U9: 74LS244; SOP-20_L12.6-W5.3-P1.27-LS7.8-BL; LCSC Part C22374097
U10: 74HCT240; TSSOP-20_L6.5-W4.4-P0.65-LS6.5-BL; LCSC Part C543088
U13, U32, U33: 74HCT244; TSSOP-20_L6.5-W4.4-P0.65-LS6.4-BL; LCSC Part C131088
U14, U16: 74F138; DIP-16_W7.62mm
U15, U29, U101: 74HCT138; TSSOP-16_L5.0-W4.4-P0.65-LS6.4-BL; LCSC Part C8115
U17, U18, U19, U20: 7438; DIP-14_W7.62mm
U21, U22, U102, U103: 74LS123; SOIC-16_L9.9-W3.9-P1.27-LS6.0-BL; LCSC Part C234231
U23: 74HCT165; SOIC-16_L9.9-W3.9-P1.27-LS6.0-BL; LCSC Part C456131
U25: 74HCT164; TSSOP-14_L5.0-W4.4-P0.65-LS6.4-BL; LCSC Part C2908835
U26: 74F163; SOIC-16_L9.9-W3.9-P1.27-LS6.0-BL; LCSC Part C2675415
U27: 74HCT393; SO-14_L8.7-W3.9-P1.27-LS6.0-BL; LCSC Part C547642
U28, U30: 74HCT74; SO-14_L8.9-W3.9-P1.27-LS6.0-BL; LCSC Part C686657
U36: 75107; DIP-14_W7.62mm
U37: 75110; DIP-14_W7.62mm
U38, U44: 74HCT04; TSSOP-14_L5.0-W4.4-P0.65-LS6.4-BL; LCSC Part C131695
U39: 74F04; SOIC-14_L8.7-W3.9-P1.27-LS6.0-BL; LCSC Part C7159
U40: 74F00; SOIC-14_L8.7-W3.9-P1.27-LS6.0-BL; LCSC Part C7158
U41, U42: 74F08; SSOP-14_L6.2-W5.3-P0.65-LS7.8-BL-1; LCSC Part C4469192
U43: 74HCT32; TSSOP-14_L5.0-W4.4-P0.65-LS6.4-BL; LCSC Part C547595
U45: 74HCT14; TSSOP-14_L5.0-W4.4-P0.65-LS6.4-BL; LCSC Part C5968
U46: 74HCT163; SOIC-16_L9.9-W3.9-P1.27-LS6.0-BL; LCSC Part C2866759
U47: 74HCT02; SOIC-14_L8.7-W3.9-P1.27-LS6.0-BL; LCSC Part C471050
U48: 7905; TO-252-2_L6.6-W6.1-P4.57-LS10.1-BR-CW; LCSC Part C19273129
U50: 3.3V LDO Reg; SOIC-8_L5.0-W4.0-P1.27-LS6.0-BL; LCSC Part C7301
U104: 74HCT00; TSSOP-14_L5.0-W4.4-P0.65-LS6.4-BL; LCSC Part C8206

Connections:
+5V: C1.1, C6.1, C7.1, C8.1, C9.1, C10.1, C11.1, C18.1, C19.1, C24.2, C25.2, C26.2, C27.2, C28.2, C29.2, C30.2, C31.2, C32.2, C36.2, C37.2, C38.1, C40.1, C41.1, C42.1, C44.2, C45.2, C46.2, C47.2, C48.2, C49.2, C50.2, C51.2, C52.2, C53.2, C54.2, C55.2, C56.2, C57.2, C58.2, C59.2, C60.2, C61.2, C62.2, C63.2, C64.2, C65.2, C66.2, C67.2, C68.2, C69.2, C71.1, C74.1, C75.1, C76.1, C77.2, C78.2, D1.1 (K), J2.41, J2.42, LED1.1 (A), LED2.1 (A), LED3.1 (A), LED4.1 (A), LED5.1 (A), LED6.1 (+), LED7.1 (A), LED8.1 (A), LED9.1 (+), LED11.1 (+), LED12.1 (+), LED13.1 (+), OSC1.1 (EOH), OSC1.4 (VCC), OSC2.1 (EOH), OSC2.4 (VCC), P7.5 (VOUT), R11.2, R12.2, R13.2, R14.2, R15.1, R18.2, R23.1, R24.1, R25.1, R26.1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
-5V: C73.2, U36.13, U37.11, U48.3 (OUT)
/+FAULT: U8.19 (O7), U41.5, U104.1, U104.2
/+RGATE: U9.8 (I3a), U37.1, U37.3, U44.12, U47.8, U102.2 (B)
/+RWDAT: J1.7, RP2.1 (R1.1), U36.12, U37.13
/+SEL: U8.5 (O1), U17.1, U17.4, U17.9, U17.12, U18.1, U18.4, U18.12, U36.6, U37.4, U37.5, U37.10, U39.3, U41.4, U42.12, U101.6 (E2)
/+SYSCLK: J1.11, RP2.5 (R3.1), U37.8
/+WGATE: U9.11 (I0b), U25.9 (~MR), U36.8, U44.10, U47.9, U102.10 (B)
/-RWDAT: J1.8, RP2.3 (R2.1), U36.11, U37.12
/-SEL: R31.2, U29.4 (~E0), U39.4
/-SYSCLK: J1.12, RP2.7 (R4.1), U37.9
/AddressBus0: U1.30 (A0), U2.10 (A0), U3.21 (A0), U4.24 (A0)
/AddressBus1: U1.31 (A1), U2.9 (A1), U3.23 (A1), U4.1 (A1)
/AddressBus2: U1.32 (A2), U2.8 (A2), U3.24 (A2), U4.2 (A2)
/AddressBus3: U1.33 (A3), U2.7 (A3), U3.25 (A3), U4.3 (A3)
/AddressBus4: U1.34 (A4), U2.6 (A4), U3.26 (A4), U14.1 (A0), U15.1 (A0), U16.1 (A0)
/AddressBus5: U1.35 (A5), U2.5 (A5), U3.1 (A5), U14.2 (A1), U15.2 (A1), U16.2 (A1)
/AddressBus6: U1.36 (A6), U2.4 (A6), U3.2 (A6), U14.3 (A2), U16.3 (A2)
/AddressBus7: U1.37 (A7), U2.3 (A7), U3.3 (A7), U15.6 (E2), U39.13
/AddressBus8: U1.38 (A8), U2.25 (A8), U3.4 (A8)
/AddressBus9: U1.39 (A9), U2.24 (A9), U3.5 (A9)
/AddressBus10: U1.40 (A10), U2.21 (A10), U3.6 (A10)
/AddressBus11: U1.1 (A11), U2.23 (A11), U3.7 (A11)
/AddressBus12: U1.2 (A12), U2.2 (A12), U3.8 (A12)
/AddressBus13: U1.3 (A13), U2.26 (A13), U3.9 (A13)
/AddressBus14: U1.4 (A14), U2.1 (A14), U3.10 (A14)
/CMDRW: J1.20, RP1.12 (R5.2), U9.4 (I1a), U42.10, U47.11
/DMARQ: J2.21, J4.21, R48.2
/DataBus0: U1.14 (D0), U2.11 (D0), U3.11 (I/O0), U4.17 (D0), U8.3 (D0), U9.18 (O0a), U10.18 (1Y0), U11.3 (D0), U13.18 (O0a), U23.11 (D0), U24.2 (O0), U31.3 (D0), U32.2 (I0a), U33.18 (O0a), U34.2 (O0), U35.3 (D0)
/DataBus1: U1.15 (D1), U2.12 (D1), U3.12 (I/O1), U4.8 (D1), U8.18 (D7), U9.3 (O3b), U10.3 (2Y0), U11.18 (D7), U13.3 (O3b), U23.12 (D1), U24.19 (O7), U31.18 (D7), U32.17 (I3b), U33.3 (O3b), U34.19 (O7), U35.18 (D7)
/DataBus2: U1.12 (D2), U2.13 (D2), U3.13 (I/O2), U4.16 (D2), U8.4 (D1), U9.16 (O1a), U10.16 (1Y1), U11.4 (D1), U13.16 (O1a), U23.13 (D2), U24.5 (O1), U31.4 (D1), U32.4 (I1a), U33.16 (O1a), U34.5 (O1), U35.4 (D1)
/DataBus3: U1.8 (D3), U2.15 (D3), U3.15 (I/O3), U4.9 (D3), U8.17 (D6), U9.5 (O2b), U10.5 (2Y1), U11.17 (D6), U13.5 (O2b), U23.14 (D3), U24.16 (O6), U31.17 (D6), U32.15 (I2b), U33.5 (O2b), U34.16 (O6), U35.17 (D6)
/DataBus4: U1.7 (D4), U2.16 (D4), U3.16 (I/O4), U4.15 (D4), U8.7 (D2), U9.14 (O2a), U10.14 (1Y2), U11.7 (D2), U13.14 (O2a), U23.3 (D4), U24.6 (O2), U31.7 (D2), U32.6 (I2a), U33.14 (O2a), U34.6 (O2), U35.7 (D2)
/DataBus5: U1.9 (D5), U2.17 (D5), U3.17 (I/O5), U4.10 (D5), U8.14 (D5), U9.7 (O1b), U10.7 (2Y2), U11.14 (D5), U13.7 (O1b), U23.4 (D5), U24.15 (O5), U31.14 (D5), U32.13 (I1b), U33.7 (O1b), U34.15 (O5), U35.14 (D5)
/DataBus6: U1.10 (D6), U2.18 (D6), U3.18 (I/O6), U4.14 (D6), U8.8 (D3), U9.12 (O3a), U10.12 (1Y3), U11.8 (D3), U13.12 (O3a), U23.5 (D6), U24.9 (O3), U31.8 (D3), U32.8 (I3a), U33.12 (O3a), U34.9 (O3), U35.8 (D3)
/DataBus7: U1.13 (D7), U2.19 (D7), U3.19 (I/O7), U4.11 (D7), U8.13 (D4), U9.9 (O0b), U10.9 (2Y3), U11.13 (D4), U13.9 (O0b), U23.6 (D7), U24.12 (O4), U31.13 (D4), U32.11 (I0b), U33.9 (O0b), U34.12 (O4), U35.13 (D4)
/IDEDataBus0: J2.17, J4.17, U32.18 (O0a), U34.3 (D0)
/IDEDataBus1: J2.15, J4.15, U32.3 (O3b), U34.18 (D7)
/IDEDataBus2: J2.13, J4.13, U32.16 (O1a), U34.4 (D1)
/IDEDataBus3: J2.11, J4.11, U32.5 (O2b), U34.17 (D6)
/IDEDataBus4: J2.9, J4.9, U32.14 (O2a), U34.7 (D2)
/IDEDataBus5: J2.7, J4.7, U32.7 (O1b), U34.14 (D5)
/IDEDataBus6: J2.5, J4.5, U32.12 (O3a), U34.8 (D3)
/IDEDataBus7: J2.3, J4.3, U32.9 (O0b), U34.13 (D4)
/IDEDataBus8: J2.4, J4.4, U31.2 (O0), U33.2 (I0a)
/IDEDataBus9: J2.6, J4.6, U31.19 (O7), U33.17 (I3b)
/IDEDataBus10: J2.8, J4.8, U31.5 (O1), U33.4 (I1a)
/IDEDataBus11: J2.10, J4.10, U31.16 (O6), U33.15 (I2b)
/IDEDataBus12: J2.12, J4.12, U31.6 (O2), U33.6 (I2a)
/IDEDataBus13: J2.14, J4.14, U31.15 (O5), U33.13 (I1b)
/IDEDataBus14: J2.16, J4.16, U31.9 (O3), U33.8 (I3a)
/IDEDataBus15: J2.18, J4.18, U31.12 (O4), U33.11 (I0b)
/IMIBus0: J1.33, RP1.2 (R2.1), U10.2 (1A0), U20.11, U29.1 (A0)
/IMIBus1: J1.34, RP1.3 (R3.1), U10.17 (2A0), U20.8, U29.2 (A1)
/IMIBus2: J1.31, RP1.4 (R4.1), U10.4 (1A1), U20.6
/IMIBus3: J1.32, RP1.5 (R5.1), U10.15 (2A1), U20.3
/IMIBus4: J1.29, RP1.6 (R6.1), U10.6 (1A2), U19.11
/IMIBus5: J1.30, RP1.7 (R7.1), U10.13 (2A2), U19.8
/IMIBus6: J1.27, RP1.9 (R8.2), U10.8 (1A3), U19.6
/IMIBus7: J1.28, RP1.10 (R7.2), U10.11 (2A3), U19.3
/INTRQ: J2.31, J4.31, R49.2
/IORDY: J2.27, J4.27, R46.2
/RP1-11: J1.19, RP1.11 (R6.2), U9.15 (I2b), U29.3 (A2), U47.12
/RP1-13: J1.22, RP1.13 (R4.2), U9.17 (I3b), U29.5 (~E1)
/RP1-14: J1.21, RP1.14 (R3.2), U9.2 (I0a), U42.9
/RXA: J3.3, U5.13 (R1IN)
/RXB: J3.5, U5.8 (R2IN)
/S100_RESET_P75: D3.1 (K), P1.75 (RESET*)
/SUA0: U8.6 (O2), U17.13, U101.1 (A0)
/SUA1: U8.15 (O5), U17.10, U101.2 (A1)
/SUA2: U8.9 (O3), U17.5, U101.3 (A2)
/SUA3: U8.12 (O4), U17.2, U101.4 (~E0), U101.5 (~E1)
/TOF: U15.12 (~Y3)
/TXA: J3.2, U5.14 (T1OUT)
/TXB: J3.4, U5.7 (T2OUT)
/~681: U4.22 (~CE), U41.8, U42.2
/~D10R: J2.25, J4.25, R45.1
/~D10W: J2.23, J4.23, R44.1
/~DASP: J2.39, J4.39, R50.1
/~DMACK: J2.29, J4.29, R47.2
/~IORQ: U1.20 (~IORQ), U39.11
/~IO: U14.4 (E1), U15.4 (~E0), U16.4 (E1), U40.6
/~M1: U1.27 (~M1), U40.4
/~R00h: U10.1 (1OE), U10.19 (2OE), U14.15 (O0)
/~R10h: U9.1 (OEa), U9.19 (OEb), U14.14 (O1)
/~R20h: U14.13 (O2)
/~R30h: U13.1 (OEa), U13.19 (OEb), U14.12 (O3)
/~R50h: U14.10 (O5), U22.10 (B)
/~R60h: C35.1, U14.9 (O6), U24.1 (OE)
/~R70h: U14.7 (O7), U41.10
/~R: U1.21 (~RD), U4.5 (RDN), U14.5 (E2)
/~SEEK COMPLETE: U22.4 (~Q), U104.10
/~START SEEK: U14.11 (O4), U103.1 (A), U104.4
/~TOF: U103.9 (A)
/~W00h: U11.11 (Cp), U16.15 (O0)
/~W10h: U8.11 (Cp), U16.14 (O1)
/~W20h: U16.13 (O2), U22.1 (A)
/~W30h: U16.12 (O3), U21.10 (B), U41.1
/~W40h: U16.11 (O4), U41.2
/~W50h: U7.10 (~S), U16.10 (O5)
/~W60h: C33.2, R39.2, U16.9 (O6)
/~W: U1.22 (~WR), U3.27 (~WE), U4.4 (WRN), U15.3 (A2), U16.5 (E2)
GND: C1.2, C6.2, C7.2, C8.2, C9.2, C10.2, C11.2, C12.2, C13.2, C14.2, C17.2, C19.2, C24.1, C25.1, C26.1, C27.1, C28.1, C29.1, C30.1, C31.1, C32.1, C34.2, C36.1, C37.1, C38.2, C40.2, C41.2, C42.2, C43.2, C44.1, C45.1, C46.1, C47.1, C48.1, C49.1, C50.1, C51.1, C52.1, C53.1, C54.1, C55.1, C56.1, C57.1, C58.1, C59.1, C60.1, C61.1, C62.1, C63.1, C64.1, C65.1, C66.1, C67.1, C68.1, C69.1, C70.2, C71.2, C72.1, C73.1, C74.2, C75.2, C76.2, C77.1, C78.1, J1.1, J1.2, J1.3, J1.13, J1.14, J1.23, J1.24, J1.26, J2.2, J2.19, J2.22, J2.24, J2.26, J2.28, J2.30, J2.40, J2.43, J3.1, J4.2, J4.19, J4.22, J4.24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
unnamed: BZ1.1 (+), R10.2
unnamed: BZ1.2 (-), J6.1
unnamed: C33.1, R37.2, R38.1, U45.11
unnamed: C35.2, R41.2, U45.5
unnamed: C39.1, U47.10
unnamed: C39.2, R52.2, R53.1, U45.3
unnamed: C12.1, D1.2 (A), D3.2 (A), R18.1, U45.1
unnamed: J1.5, U17.3
unnamed: J1.6, U17.6
unnamed: J1.9, U17.8
unnamed: J1.10, U17.11
unnamed: J1.15, U18.3
unnamed: J1.16, U18.6
unnamed: J1.17, U18.8
unnamed: J2.1, J4.1, U35.12 (O4)
unnamed: J2.33, J4.33, U35.16 (O6)
unnamed: J2.35, J4.35, U35.5 (O1)
unnamed: J2.36, J4.36, U35.6 (O2)
unnamed: J2.37, J4.37, U35.2 (O0)
unnamed: J2.38, J4.38, U35.19 (O7)
unnamed: C70.1, J5.1, P1.1 (+8_V), P1.51 (+8_V), P7.3 (VIN), TP10.1
unnamed: C72.2, J5.2, P1.52 (-16_V), TP13.1, U48.2 (IN)
unnamed: J6.2, U104.5, U104.8
unnamed: LED1.2 (K), R1.2
unnamed: LED2.2 (K), R2.2
unnamed: LED3.2 (K), R3.2
unnamed: LED4.2 (K), R4.2
unnamed: LED5.2 (K), R5.2
unnamed: LED6.2 (-), R6.2
unnamed: LED7.2 (K), R7.2
unnamed: LED8.2 (K), R8.2
unnamed: LED9.2 (-), R9.2
unnamed: LED11.2 (-), R22.2
unnamed: LED12.2 (-), R31.1
unnamed: LED13.2 (-), R50.2
unnamed: OSC1.3 (OUT), U4.20 (X1)
unnamed: OSC2.3 (OUT), U28.11 (C)
unnamed: C13.1, C14.1, OSC3.1 (EOH), OSC3.4 (VCC), U50.2 (OUT), U50.3 (OUT), U50.6 (OUT), U50.7 (OUT)
unnamed: OSC3.3 (OUT), TP7.1, U26.2 (CP), U46.2 (CP)
unnamed: P1.2 (+16_V), TP12.1
unnamed: Q1.1 (BASE), R32.2
unnamed: J1.18, Q1.2 (COLLECTOR)
unnamed: R9.1, U104.3
unnamed: R10.1, U104.6, U104.9
unnamed: R32.1, R33.2, U41.6
unnamed: R44.2, U38.1, U43.6
unnamed: R45.2, U38.8
unnamed: R51.1, U42.6
unnamed: TP3.1, U40.9, U45.6
unnamed: U1.6 (~CLK), U6.3 (C), U6.11 (C), U7.3 (C), U28.9 (Q)
unnamed: R15.2, U1.16 (~INT)
unnamed: U1.19 (~MREQ), U2.20 (~CS), U3.20 (~CE), U39.1
unnamed: U1.26 (~RESET), U7.13 (~R), U45.12
unnamed: U1.24 (~WAIT), U6.5 (Q), U6.12 (D)
unnamed: R22.1, U2.22 (~OE), U7.9 (Q)
unnamed: U3.22 (~OE), U7.8 (~Q), U40.2
unnamed: U4.21 (RST), U45.2, U45.13
unnamed: U4.19 (RXA), U5.12 (R1OUT)
unnamed: U4.6 (RXB), U5.9 (R2OUT)
unnamed: U4.18 (TXA), U5.11 (T1IN)
unnamed: U4.7 (TXB), U5.10 (T2IN)
unnamed: C15.1, U5.1 (C1+)
unnamed: C15.2, U5.3 (C1-)
unnamed: C16.1, U5.4 (C2+)
unnamed: C16.2, U5.5 (C2-)
unnamed: C18.2, U5.2 (VS+)
unnamed: C17.1, U5.6 (VS-)
unnamed: U6.2 (D), U42.3
unnamed: U6.4 (~S), U7.5 (Q)
unnamed: U6.9 (Q), U7.2 (D)
unnamed: U8.2 (O0), U18.13
unnamed: J1.25, U9.6 (I2a), U18.11
unnamed: U11.2 (O0), U20.13
unnamed: U11.5 (O1), U20.5
unnamed: U11.6 (O2), U19.13
unnamed: U11.9 (O3), U19.5
unnamed: U11.12 (O4), U19.2
unnamed: U11.15 (O5), U19.10
unnamed: U11.16 (O6), U20.2
unnamed: U11.19 (O7), U20.10
unnamed: R23.2, SW1.1, U13.2 (I0a)
unnamed: TP1.1, U13.11 (I0b), U22.5 (Q)
unnamed: R24.2, SW1.3, U13.4 (I1a)
unnamed: R27.2, SW1.6, U13.13 (I1b)
unnamed: R25.2, SW1.5, U13.6 (I2a)
unnamed: R28.2, SW1.4, U13.15 (I2b)
unnamed: R26.2, SW1.7, U13.8 (I3a)
unnamed: R29.2, SW1.2, U13.17 (I3b)
unnamed: U14.6 (E3), U16.6 (E3), U39.12
unnamed: U15.15 (~Y0), U42.4, U43.1, U43.5
unnamed: U15.14 (~Y1), U35.11 (Cp)
unnamed: U15.13 (~Y2), U30.1 (~R)
unnamed: U15.11 (~Y4), U42.5, U43.10, U43.13
unnamed: U16.7 (O7), U41.9
unnamed: U19.1, U19.4, U19.9, U19.12, U20.1, U20.4, U20.9, U20.12, U42.11
unnamed: U21.2 (B), U41.3
unnamed: C21.2, U21.14 (Cext)
unnamed: U18.2, U21.13 (Q)
unnamed: C21.1, R34.2, U21.15 (RCext)
unnamed: C22.2, U21.6 (Cext)
unnamed: U18.5, U21.5 (Q)
unnamed: C22.1, R35.2, U21.7 (RCext)
unnamed: C23.2, U22.14 (Cext)
unnamed: U18.9, U18.10, U22.13 (Q)
unnamed: C23.1, R36.2, U22.15 (RCext)
unnamed: C20.2, U22.6 (Cext)
unnamed: C20.1, R30.2, U22.7 (RCext)
unnamed: U23.2 (CP), U39.9, U47.4
unnamed: U23.9 (Q7), U37.2
unnamed: TP2.1, U23.1 (~PL), U28.3 (C), U45.8
unnamed: U24.11 (Cp), U27.8 (Q3), U39.5
unnamed: U24.3 (D0), U25.3 (Q0)
unnamed: U24.4 (D1), U25.5 (Q2)
unnamed: U24.7 (D2), U25.10 (Q4)
unnamed: U24.8 (D3), U25.12 (Q6)
unnamed: U24.13 (D4), U25.13 (Q7)
unnamed: U24.14 (D5), U25.11 (Q5)
unnamed: U24.17 (D6), U25.6 (Q3)
unnamed: U24.18 (D7), U25.4 (Q1)
unnamed: U25.8 (CP), U37.6, U39.8
unnamed: U25.1 (DSA), U36.9
unnamed: U26.13 (Q1), U27.13 (CP), U47.5
unnamed: U26.1 (~MR), U39.6
unnamed: U27.1 (CP), U46.13 (Q1), U47.6
unnamed: TP6.1, U27.2 (MR), U45.4
unnamed: U27.5 (Q2), U40.13
unnamed: U27.6 (Q3), U40.12
unnamed: TP5.1, U27.12 (MR), U40.8
unnamed: R40.1, TP4.1, U28.6 (~Q), U40.10
unnamed: C34.1, R40.2, U28.1 (~R)
unnamed: U28.8 (~Q), U28.12 (D)
unnamed: U29.6 (E2), U42.8
unnamed: U29.14 (~Y1), U44.13
unnamed: U29.13 (~Y2), U44.11
unnamed: C43.1, R51.2, U30.3 (C)
unnamed: U30.2 (D), U30.6 (~Q), U43.4, U43.12
unnamed: U30.5 (Q), U43.2, U43.9
unnamed: U31.11 (Cp), U43.3
unnamed: U31.1 (OE), U32.1 (OEa), U32.19 (OEb), U38.4
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

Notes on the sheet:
Jumper to enable buzzer
IDE Interface
Spare
WDI I/O
Processor
Optional acoustic feedback (click on seek)
Serial-Parallel Conversion
Optional diode
Display & Sound
Pololu 5Volt (D24V22F5)
SELECTED
Resistor value up to user, depending on desired volume

Board: 6 copper layers, 219 parts (0 on the bottom side), 265 nets, no tracks yet.

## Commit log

2026-03-01 routing complete
    [W2I-S100-B_Silkscreen.gbo, W2I-S100-Component.gtl, W2I-S100-Copper.gbl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]
2026-03-05 part replacement & autorouter complete
    [W2I-S100-B_Mask.gbs, W2I-S100-B_Paste.gbp, W2I-S100-B_Silkscreen.gbo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]
2026-03-28 3/28 updates
    swapped crystals for TH parts
    [W2I-S100-BOM.xls, W2I-S100.csv, W2I-S100.kicad_sch]
2026-03-29 final modifications
    [W2I-S100-BOM.csv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]
2026-04-04 W2I-S100 Rev 1 Final
    [W2I-S100-BOM.csv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]
2026-04-04 Initial commit
    Added images of the PCB front and back renders to the README.
2026-04-20 First prototype photo
2026-04-20 Add prototype photo to README
    Added a photo of the first prototype to the README.
